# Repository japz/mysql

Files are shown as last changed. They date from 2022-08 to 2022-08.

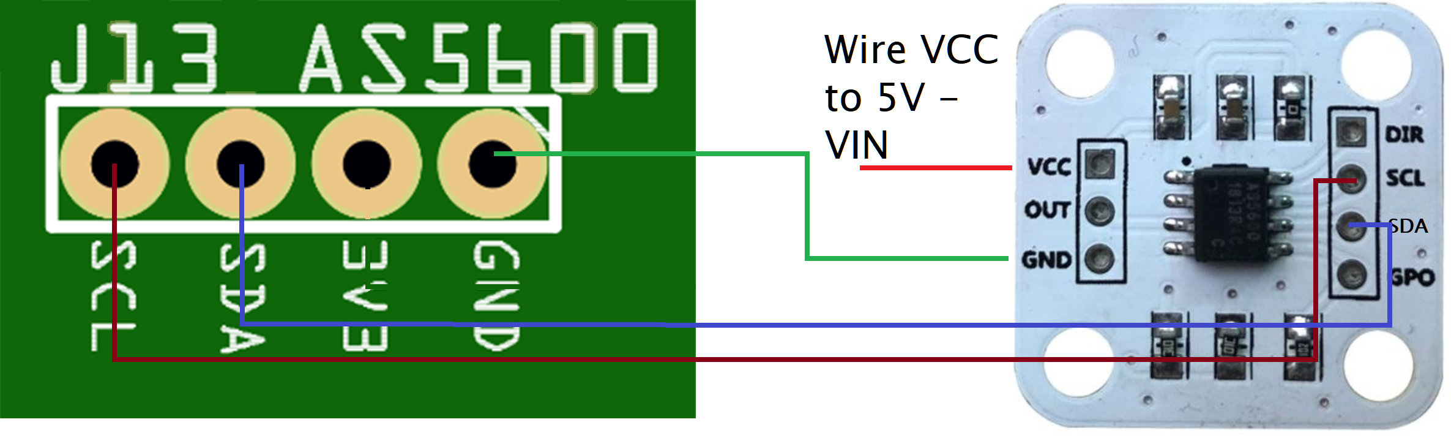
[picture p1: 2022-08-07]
Wind Direction Sensor/WINDDIRECTION3DPRINT/Wind-Direction-3DPRINT-Sensor-Wiring-Rev5-Rev6-Rev7.png

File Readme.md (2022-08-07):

# mySQM+ SPECIFICATIONS
(c) R Brown 2020-2022. All rights reserved  

## SPECIFICATIONS
 - Displays sky quality reading mag/arc-seconds
 - Use manually or via a network via TCP/IP, with logging capability
 - Web server option to provide data in a web-browser
 - Admin web-page function, most options can be enabled/disabled without reprogramming controller
 - Comprehensive manual
 - Easy to expand, examples of using remote iOT sensors
 - use mySQMWeb feature to provide running of web-based graphical interface on Pi
 - Settings saved in SPIFFS, remembered when power is off
 - SQM reading
 - Lux reading
 - NELM reading
 - Rain sensor
 - GPS [NEO-6M]
 - JSON support
 - MQTT support, publish values to an MQTT Broker, subscribe to topics
 - Weather Underground support
 - Real Time Clock [RTC] support [DS1307]
 - Network Time Protocol [NTP] support, Sync RTC to NTP data
 - OTA [Over the Air] update support
 - Ambient temp, dewpoint, humidity, pressure
 - IR Sky temp, IR Sky ambient temp
 - Cloud sensor and modelling indicating Clear, Cloudy and Percentage
 - Anemometer Wind speed sensor [multiple types supported] [3d print version available]
 - Wind direction sensor [multiple types supported] [3d print version available]
 - Wind Chill Factor
 - Beaufort Scale for Windspeed
 - Rain Bucket Gauge
 - OLED Text and Graphic display
 - Support for Sparkfun SENS-08942 Weather Kit [Anemometer, Wind Direction, Rain Bucket Gauge]
 - Support for Misol Weather Kit [Anemometer, Wind Direction, Rain Bucket Gauge]
 - PCB [gerbers available online for free]
 - Web-browser for remote operation
 - Windows application (Windows 11, 64 bit)
 - Linux application and source code
 - ASCOM OC driver, tested with NINA
 - Support for myESP32 Daughter Board's with remote sensors for Rainfall, Lightning and UV
 - Requires 12V PSU at 2A

## PCB
PCB Gerbers free, upload the Gerber files to any on-line PCB facility

## CONTRIBUTIONS
To support ongoing development please send your donation via https://PayPal.com to user rbb1brown@gmail.com (Robert Brown).

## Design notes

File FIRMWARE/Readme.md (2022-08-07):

# mySQM+ SPECIFICATIONS
(c) R Brown 2020-2022. All rights reserved  

# FIRMWARE
 - Download the firmware zip file
   https://sourceforge.net/projects/mysqmproesp32/files/FIRMWARE/

 - Extract the files
 - Install the required library myOLED
 - Download/add the required Additonal libraries
 - Download/install the Sketch data file upload tool
 - Specify the configuration in the configuration file
 - Program the controller
 - Upload the sketch data files

# APPLICATIONS
 - ASCOM OC Driver 
  https://sourceforge.net/projects/mysqmproesp32/files/APPLICATIONS/ASCOM/
 - Linux 
  https://sourceforge.net/projects/mysqmproesp32/files/APPLICATIONS/LINUX/
 - Windows
  https://sourceforge.net/projects/mysqmproesp32/files/APPLICATIONS/WINDOWS/
  - Documentation
  https://sourceforge.net/projects/mysqmproesp32/files/DOCUMENTATION/

Root Folder 
https://sourceforge.net/projects/mysqmproesp32/files/

 - Support for myESP32 Daughter Board's with remote sensors for Rainfall, Lightning and UV
 - Requires 12V PSU at 2A

## PCB
PCB Gerbers free, upload the Gerber files to any on-line PCB facility

## CONTRIBUTIONS
To support ongoing development please send your donation via https://PayPal.com to user rbb1brown@gmail.com (Robert Brown).

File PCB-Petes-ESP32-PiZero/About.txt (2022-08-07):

Pete's PCB for ESP32 + Pi Zero on one board

The Pi-Zero is to run mySQMWEB.

The ESP32 runs the various sensor devices, webserver and other functions.

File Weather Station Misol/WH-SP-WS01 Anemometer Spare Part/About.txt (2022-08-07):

https://www.aliexpress.com/item/32793283814.html

Spare part (outdoor unit) for Professional Wireless Weather Station, WH-SP-WS02

US $41.38

1). thermo-hygro sensor (1 unit)
2). Wind direction sensor (1 unit)
3). Rain gauge sensor (1 unit)
4). Wind speed sensor (1 unit)
5). Installation rack (1 unit)

https://openweatherstation.com/ows/index.php

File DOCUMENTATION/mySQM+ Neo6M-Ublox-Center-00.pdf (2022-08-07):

# mySQM+ NEO-6M GPS AND UBLOX CENTER

14 February 2022
(c) R BROWN 2022
All rights reserved.

This document outlines the initial configuration of the NEO-6M GPS module using UBLOX Center evaluation software.

## UBLOX CENTER FOR WINDOWS

I am using uBLOX-Center Windows exe 21.09 which you will need to download.

### Connection

Connect up GPS unit to a RS232-USB convertor as indicated below

NEO6M-Pin | RS232/USB
VCC | VCC
RXD | TXD
TXD | RXD
GND | GND

## START UBLOX-CENTER

### Set the COM Port Speed to 9600

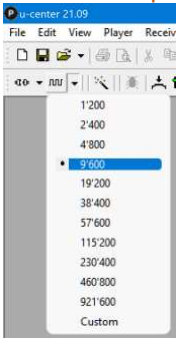
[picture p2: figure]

### Set the COM Port

Click on the Down arrow of the Com Port, select the port and Click Connect

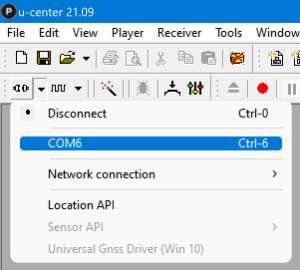
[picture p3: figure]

### Open the text console

Use the menu View-Text Console. You may see a heap of text messages in the Text Console window

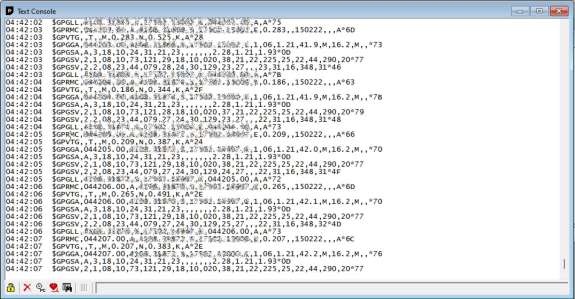
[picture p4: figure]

### Open the Message console

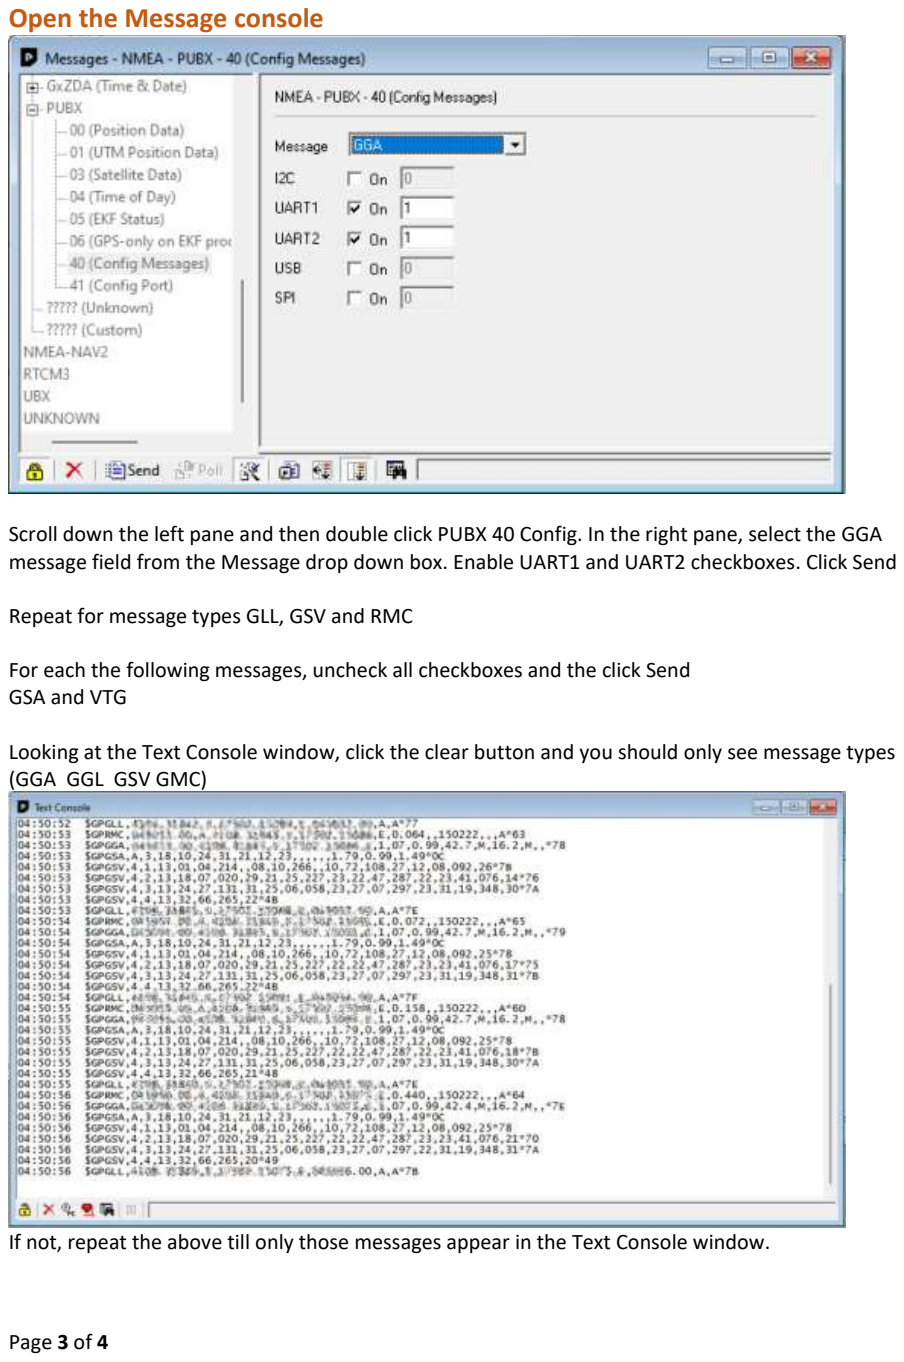
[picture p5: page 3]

Scroll down the left pane and then double click PUBX 40 Config. In the right pane, select the GGA message field from the Message drop down box. Enable UART1 and UART2 checkboxes. Click Send

Repeat for message types GLL, GSV and RMC

For each the following messages, uncheck all checkboxes and the click Send
GSA and VTG

Looking at the Text Console window, click the clear button and you should only see message types (GGA GGL GSV GMC)

If not, repeat the above till only those messages appear in the Text Console window.

### DOCKING WINDOWS

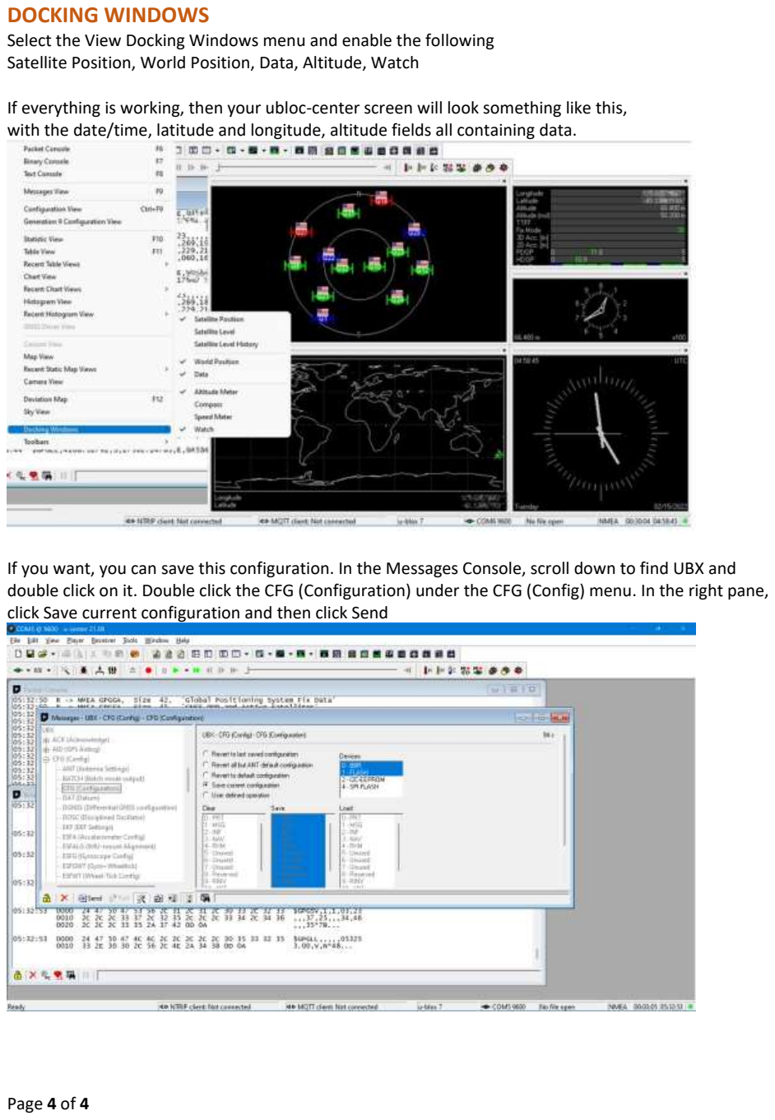
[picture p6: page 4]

Select the View Docking Windows menu and enable the following
Satellite Position, World Position, Data, Altitude, Watch

If everything is working, then your ubloc-center screen will look something like this, with the date/time, latitude and longitude, altitude fields all containing data.

If you want, you can save this configuration. In the Messages Console, scroll down to find UBX and double click on it. Double click the CFG (Configuration) under the CFG (Config) menu. In the right pane, click Save current configuration and then click Send

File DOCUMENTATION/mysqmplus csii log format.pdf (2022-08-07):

### mySQM+ CLOUD SENSOR II FORMAT

- Connect to controller
- Enable checkbox CSII Format
- Set logging interval
- Enable Automate logging
Date/Time | yyyy-MM-dd HH:mm:ss.ss
Temperature | C | values in Celsius
Wind Velocity | m | meters per second
Sky temperature | IRObject Temperature
Ambient temperature | IRAmbientTemp
Sensor case temperature | bme280temperature
Wind Speed | in m/s
Humidity | bme280humidity
Dew Point | bme280dewpoint
Heater % | 0
Rain Flag | Raining or Not raining
Seconds since the last valid data | timerinterval tick / 1000
Now | 038506.08846
c | sky state | skystate
w | wind condition | 0
r | rain condition | Raining or Not raining
d | daylight condition | lux
C | roof close | 0
A | Alert | 0

### Skystate

Cloud cover percentage ( 0-100% ) is used to generate the cloud condition value in the CSII log.

// 94 c sky state, cloudUnknown = 0, cloudClear = 1, cloudCloudy = 2, cloudVeryCloudy = 3
If cloudcover > 59.9 then cloudstate = 3; | // cloudVeryCloudy
else if cloudcover > 33.9 AND cloudcover < 59.9 then cloudstate = 2; | // cloudCloudy
else cloudstate = 1 | // cloudClear

if cloudcover > cloudVeryCloudy then cloudstate = 3
else if cloudcover > cloudCloudy AND cloudcover < cloudVeryCloudy then cloudstate = 2 else cloudstate = 1

cloudVeryCloudy is the top boundary [default is 59.9]. Any cloudcover value greater than this results in a value of 3 for cloudstate

cloudCloudy is the middle boundary [default is 33.9]. Any cloudcover value greater than the cloudCloudy boundary value AND if the cloudcover value is less than the cloudVeryCloudy value, results in a value of 2 for cloudstate

cloudClear is the lower boundary. Any cloudcover less than the cloudCloudy value results in a value of 1 for cloudstate

### Wind Condition

To do this we compare windspeed (remember some sensors have a maximum limit reading of 20 m/s) against some arbitrary boundaries to generate a wind condition.

// 96 w wind condition, windUnknown = 0, windCalm = 1, windWindy = 2, windVeryWindy = 3
If windspeed >= 15.0 then windcondition = 3 | // windVeryWindy
else if windspeed >= 5.0 and windspeed < 15.0 then windcondition = 2 // windWindy
else windcondition = 1 | // windCalm

if windspeed >= windVeryWindy then windcondition = 3
else if windspeed >= windWindy and windspeed < windVeryWindy then windcondition = 2 else windcondition = 1

windVeryWindy is the top boundary [default is 15.0]. Any windspeed value greater than this results in a value of 3 for windcondition

windWindy is the middle boundary [default is 33.9]. Any windspeed value greater than the windWindy value AND less than the windVeryWindy value, results in a value of 2 for windcondition

windCalm is the lower boundary. Any windspeed value that is less than the windWindy value results in a value of 1 for windcondition

### Daylight Condition

The lux value is compared against some arbitary boundaries to generate a daylight condition.

// (100) d daylightcondition, dayUnknown = 0, dayDark = 1, dayLight = 2, dayVeryLight = 3
if lux >= 5000.0 then daylightcondition = 3 | // dayVeryLight
else if lux >= 5.0 AND lux < 5000.0 then daylightcondition = 2 | // dayLight
else daylightcondition = 1 | // dayDark

// (100) d daylightcondition, dayUnknown = 0, dayDark = 1, dayLight = 2, dayVeryLight = 3 if lux >= dayVeryLight then daylightcondition = 3
else if lux >= dayLight AND lux < dayVeryLight then daylightcondition = 2
else daylightcondition = 1

dayVeryLight is the top boundary [default is 5000.0]. Any lux value greater than this results in a value of 3 for daylightcondition

dayLight is the middle boundary [default is 5.0]. Any lux value greater than the dayLight value AND less than the dayVeryLight value, results in a value of 2 for daylightcondition

dayDark is the lower boundary. Any lux value that is less than the dayLight value results in a value of 1 for daylightcondition

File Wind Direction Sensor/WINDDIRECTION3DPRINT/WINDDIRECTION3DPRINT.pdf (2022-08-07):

1 | P a g e

## mySQMPROESP WINDDIRECTION3DPRINT SENSOR

© Robert Brown, 2020. All rights reserved.

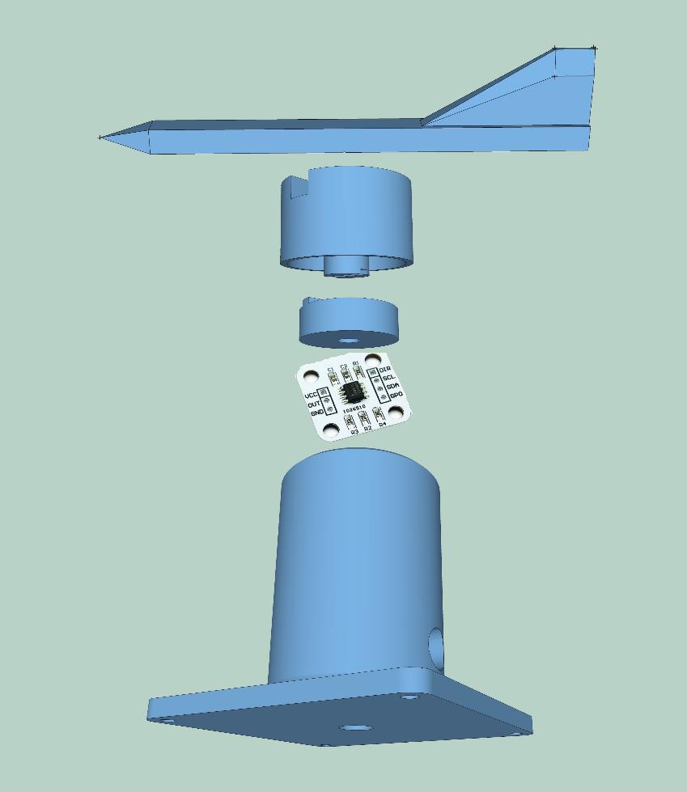
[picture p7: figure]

//TODO Replace picture with finished unit

2 | P a g e

## Contents

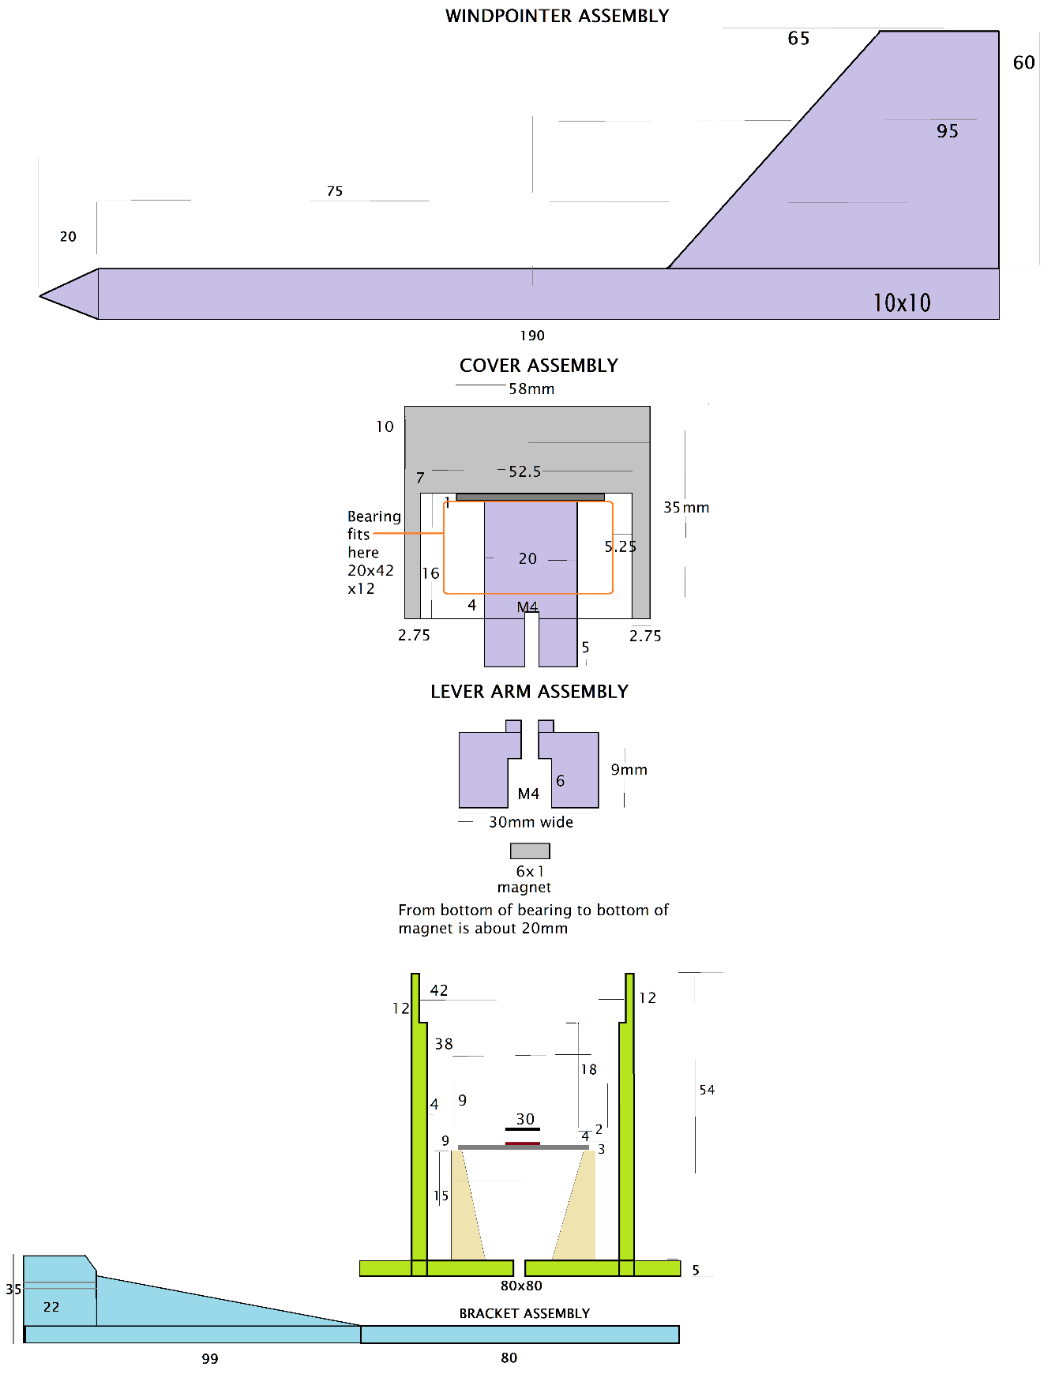
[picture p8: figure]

3 | P a g e

## OVERALL DESIGN PRINCIPLES

DIMENSIONS

4 | P a g e

WINDPOINTER TIP ASSEMBLY
The wind pointer tip has a hollow portion to allow a small lead ballast to be fitted before assembly to the front of wind pointer assembly [push interference fit – secure with super glue or hot glue]. The ballast helps in pointing ability.

WINDPOINTER ASSEMBLY
The wind vane mounts into the 10mm recess groove on the top of the cover assembly. A small notch in the wind vane arm and center M3 bolt hole helps positioning the vane appropriately on the cover assembly. There are two designs [1, 2] which have different wind vane heights. One or the other may be more suited to your local conditions [the larger height should give better results in low wind environments]

COVER ASSEMBLY

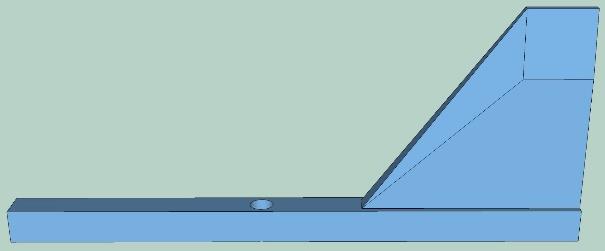
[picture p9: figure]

The cover assembly forms the rotating head of the sensor with a magnet attached. A large 6004 2RS low friction bearing is used to allow a center column diameter of 12mm, providing ample strength to handle strong winds. At the bottom of the center column is fitted a lever arm [using a slotted recess and a M4 x 10mm hex bolt]. A small round magnet [6mmx1mm] fits onto the head of the hex bolt [and secured in place with super glue or hot glue]. The cover assembly when completed is attached to the Base assembly by press fitting the bearing into the recess of the base assembly and is held in place by an interference fit.

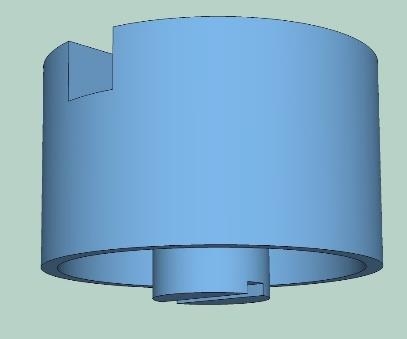
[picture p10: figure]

5 | P a g e

LEVER ARM ASSEMBLY
The lever arm is slotted to fit into a recess at the bottom of the center column of the Cover assembly. It is held in place with a M4 x 10mm hex bolt. The small 6mmx3mm magnet is fitted into a recessed hole in the bottom of the Lever Arm assembly and glued into place using hot glue. The lever arm assembly rotates as the cover assembly rotates and the magnet rotates with it, just above the sensor. If the AS5600 sensor module is mounted underneath the lever arm [sensor directly underneath magnet with air spacing 3-5mm], the magnet will pass over the module generating an angle indication representing the direction.

BASE ASSEMBLY
This assembly has an 80x80mm square plate 5mm thick to allow connection to a post or optional mounting arm bracket. A 10mm hole in the base plate allows for water drainage if by some reason water enters the assembly. A 12mm hole is provided for the GX12 4P connector. At the top of the base unit, a 42mm recess is used which will house the 6004 2RS low friction bearing. The wall thickness of the base unit is 6mm to provide strength. The AS5600 module is secured to the center of the base assembly at the specified location, ensuring that the module can detect the magnet as it passes near to it.

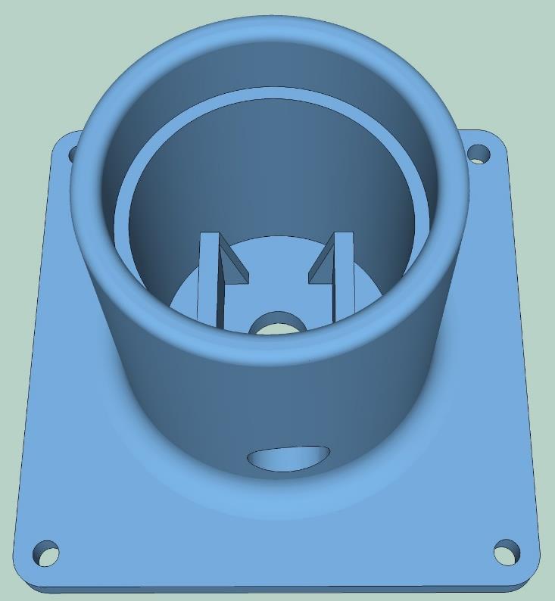
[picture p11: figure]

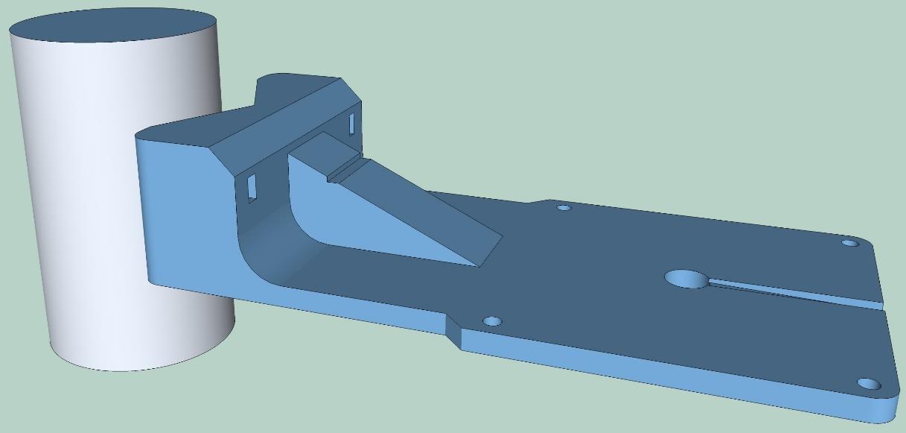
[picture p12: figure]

6 | P a g e

OPTIONAL MOUNTING BRACKET
The optional mounting bracket is for mounting the anemometer on a 2.54mm [1”] diameter pole. Two plastic zip ties can be used to secure the bracket to the pole, and the anemometer can be bolted to the bracket using [4] M4x15mm bolts.

The center hole and 4mm wide sloping trough allows water to escape.

7 | P a g e

## PARTS LIST

Quantity | Item
1 | Wind Pointer Tip Assembly
1 | Wind Pointer Assembly
1 | Base Assembly
1 | Cover Assembly
1 | Lever arm Assembly
3 | Cup and Arm Assembly
2 | Hex bolt 4M x 10mm
1 | Bearing 6004 2RS low friction, 20x42x12mm [ID/OD/Thickness]
1 | AS5600 Magnetic angle sensor and magnet
1 | Small round magnet 6mm round, 3mm deep [optional]
1 | GX12 4P Aviation male connector, waterproof, 12mm diameter
1 | GX12 4P Aviation female connector, 12mm diameter
1 | 3M 3-core weather proof cable

AS5600 Magnetic Sensor and Magnet Aliexpress DEXIANG Store https://www.aliexpress.com/item/4000861019000.html
$2.30USD

NOTE: YET TO DECIDE ON 6x1 MAGNET OR 6x3 MAGNET: NEED MORE TESTS

Magnet 6mm x 3mm N35 Round Magnets Aliexpress YCHEN Store https://www.aliexpress.com/item/32953346950.html
$2.47USD

Bearing, 20x42x12mm Alixexpress wuhushiyu Store https://www.aliexpress.com/item/4000038143034.html $2.82USD

8 | P a g e

GX12 4P Connector, male and female pair push weatherproof Aliexpress ATOPELEC Store [Note: This is for 2 sets, the other one can be used for the Wind Direction Sensor] https://www.aliexpress.com/item/32831416252.html
$2.25

9 | P a g e

## PRINT INSTRUCTIONS

Nozzle | 0.4mm
Layer Height | 0.2mm
Print Speed | 30
Infill | 10% | [Windpointer = 20%, LeverArm infill = 100%]
Supports | No | [Cover, Windpointertip, Base = Supports]

I used PLA in the prototype. PLA exposure to sun and weather will deteriorate as PLA is based on corn starch. Might be okay is painted to protect PLA from elements.

Recommend PETG for usage. PETG is strong and low shrinkage.

Do not recommend ABS due to shrinkage.

Cover Assembly
≈ 3 hours print time

WindPointerTip Assembly
≈ ½ hours print time

WindPointer Assembly
≈ 2½ hours print time

LeverArm Assembly
≈ 1 hours print time

Base Assembly
≈ 6 hours print time

Mounting Bracket Assembly
≈ 6 hours print time

10 | P a g e

## ASSEMBLY INSTRUCTIONS

WINDPOINTER TIP ASSEMBLY
- Fit a small amount of lead to the hollow recess of the pointer tip
- Secure the wind pointer tip in place by inserting it into the recess of the end of the Windpointer assembly [super glue or hot glue]

WINDPOINTER ASSEMBLY
- The wind pointer fits into the 10mm deep grove of the cover assembly
- To work effectively, there is a small groove on the base side of the wind pointer assembly. This groove is to help position the wind pointer on the cover assembly
- Position the wind pointer so the groove is over the center point of the cover assembly. Secure the wind pointer in place with an M4x10mm hex bolt [do not overtighten]

BASE ASSEMBLY
GX12 Connector wiring to AS5600 board
- Solder 4 different colored wires (80-100mm) to GX12 connector pins, slip heat shrink tube over solder connections and apply heat to shrink tube
- Using a flat file, slightly file the hole for the GX12 connector to create a slight flat surface. Do not take off too much material, only 1mm is enough
- Fit GX12 connector to the base assembly by inserting into 12mm hole at base and tighten lock nut (do not overtighten). You can use a rubber washer on the outside to prevent possible water leakage [the rubber waterproof ring is sufficient]
- Wire connector to AS5600 module [3V3 to VCC, GND, SDA and SCL], use heat-shrink tube, ensure correct wires go to correct pins
- Secure AS5600 module in place at the specified place with hot glue gun. Ensure there is a small gap (3-5mm) between the magnet and the AS5600 module.

COVER AND LEVER ARM ASSEMBLY
- Fit Bearing to Cover center column
- Connect Lever Bar to Cover center column. Secure with M4 bolt, do NOT overtighten
- Mount Magnet in Lever Bar in recess hole for M4 on top of hex bolt, secure with super glue or hot glue
- Insert cover into place in Base by positioning Cover assembly over Base and pressing downwards till bearing is fully inserted in Base assembly

11 | P a g e

ASSEMBLY PHOTOS

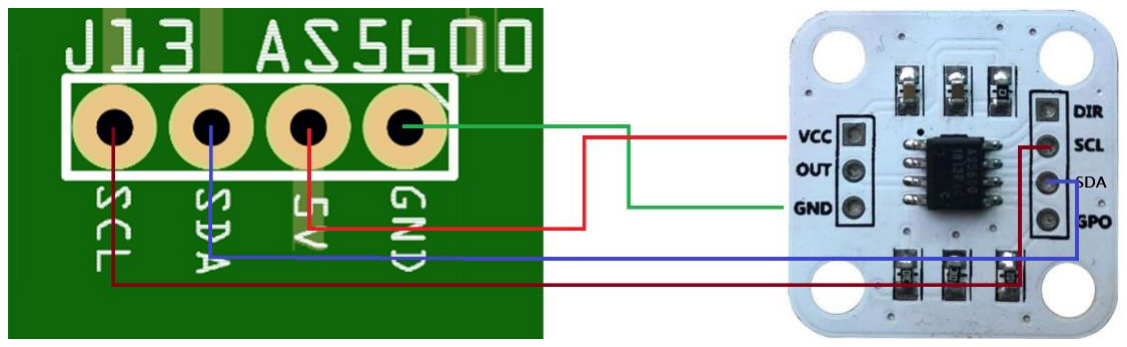
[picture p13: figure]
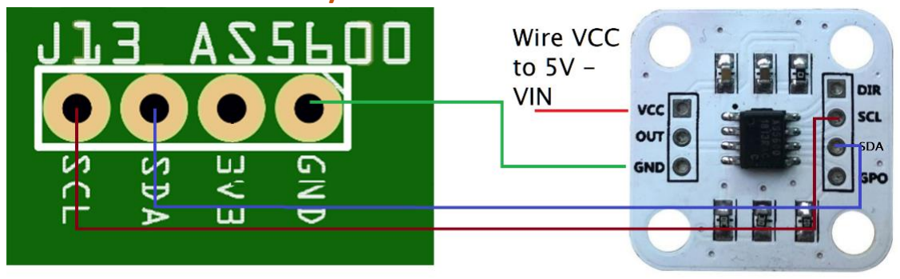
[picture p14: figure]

12 | P a g e

## WIRING

AS5600 MODULE PCB8

AS5600 MODULE PCB6/7

13 | P a g e

## TESTING THE WINDDIRECTION 3DPRINT SENSOR

Use the test program TEST_WINDDIRECTION3DPRINT.ino to test the wind direction sensor. There is no need to calibrate the unit if you followed the instructions and did not change any of the print size measurements.

Mount the sensor on the bracket and secure in place.

Use the test program determine the 0 angle position.

Carefully holding the wind vane in place, rotate the entire assembly so that the front of the wind vane is pointing due NORTH. Secure the assembly in place.

Reload the controller with the mySQMPROESP firmware, with the WINDDIRECTIONSENSOR and WINDDIRECTION3DPRINT defined in controllerconfig.h

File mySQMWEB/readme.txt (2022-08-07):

mySQMWEB
A graphical web based interface running on Apache or Raspberry PI that takes the values from a mySQM+ controller to a graphical Web page(s)

Please view the video and see values change in real time.

Please view the PDF in this zip file for instructions on how mySQMWEB can be installed.
https://sourceforge.net/projects/mysqmproesp32/files/mySQMWEB/

For further information, download the PDF for this project
https://sourceforge.net/projects/mysqmproesp32/files/DOCUMENTATION/

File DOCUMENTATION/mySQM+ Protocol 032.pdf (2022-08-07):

## mySQM+ PROTOCOL 032

May 2022
(c) R BROWN 2020-2022
All rights reserved.

APPLICABLE TO FIRMWARE 128-35+

### INTERFACE COMMANDS - TCP/IP, PORT 2121

- All commands are a string of char characters
- All send commands begin with a colon character :
- All commands have a minimum of three digits (0-9).
- All commands end with a hash character #
- Commands are zero padded from the left to three places, for example, command 2 is written as :002#

RETURN VALUES
- All return values are terminated with a #
- All return values are string characters, numbers are converted to strings before sending
Send | Meaning
:000# | Get System up-time
:001# | Reboot controller
:002# | Get MAC Address
:003# | Get SQM
:004# | Get LUX
:005# | Get NELM
:006# | Get make hay
:007# | Get services: returns Controllermode, Webserver state, TCPIP Server state,
| OTA state, MQTT client state, mqtt connect state, NTP client state,
| Management server state

FIRMWARE
:008# | Get firmware version number
:009# | Get firmware filename
:010# | Get firmware hash value

DISTANCE MODE
:011# | Get metric/imperial mode 0 = metric 1 = Imperial
:0120# | Set metric
:0121# | Set imperial

TEMPERATURE MODE
:013# | Get temperature mode (0=Celsius 1=Fahrenheit)
:0140# | Set temperature mode Celsius
:0141# | Set temperature mode Fahrenheit

TLS2591
:017# | Get tlscorrectionfactor
:018# | Get TSL2591 Gain
:019# | Get TSL2591 Integration time
:020# | Get TSL2591 sample size
:021# | Get TSL2591 averaging (0=Disabled, 1= Enabled)
:022n.n# | Set TLS sensor correction factor
:023n# | Set TSL2591 Gain
:024n# | Set TSL2591 Integration time
:025n# | Set TSL2591 sample size
:0260# | Set TSL2591 averaging OFF
:0261# | Set TSL2591 averaging ON

:027# UNUSED

BME280
:028# | Get Relative Humidity
:029# | Get Pressure
:030# | Get Ambient temperature
:031# | Get Dewpoint
:032# | Get Altitude (in meters)
:033# | Get Pressure adjusted to sea-level
:034x.x# | Set Altitude (float in meters)

MLX90614
:035# | Get IR Sensor object temperature
:036# | Get IR Sensor ambient temperature
:037# | Get Sky-State, 0=clear 1=partly cloudy 2=cloudy
:038# | Get % Cloud Cover
:039# | Get corrected sky value
:040# | Get cloud sensor k1 - k7 values k1,k2,..k7#
:041# | Get Temp Clear
:042# | Get Temp Overcast
:043# | Get Cloud-Flag-Percent
:044x,x# | Set cloud model k1..k7, separated by ,
:045n# | Set Temp Clear (-8)
:046n# | Set Temp Overcast (0)
:047n# | Set Cloud-Flag-Percent (30)

RAIN
:048# | Get rain total in mm over previous hour
:049# | Get Raining (Boolean)
:050# | Get RVout - raining analogue value (int)
:051# | Get cumulative rainfall for this current hour
:052# | Get cumulative rainfall for this current day
:053# | Do Sync Rain Bucket Gauge min/hour to RTC

WIND
:054# | Get wind speed (in meters per second)
:055# | Get wind direction
:056# | Get Wind Chill Factor
:057# | Get windspeed sensor name and wind direction sensor name
:058# | Get average windspeed last 30s
:059# | Get maximum wind speed gust last 30s
:015# | Get wind direction offset
:016n# | Set wind direction offset (unsigned int 0-359)

GPS
:060# | Get local date
:061# | Get local time
:062# | Get latitude
:063# | Get longitude
:064# | Get altitude (height in meters)
:065# | Get number of satellites
:066# | Get GPS fix
:067# | Get if GPS using static co-ordinates [0=No 1=Yes]
:068# | Get if GPS using truncated co-ordinates [0=No 1=Yes]
:069# | Get GPS Fix 'es,
| gga_quality_indicator, gll_fix_status, gll_position_mode_indicator,
| rmc_mode_indicator, gsa gsa_smode, gsa_navmode
:070# | Get GPS Static Latitude setting
:071# | Get GPS Static Longitude setting
:072# | Get GPS Format (0=DD, 1=DMS)
:0730# | Set GPS Format DD
:0731# | Set GPS Format DMS
:0740# | Set GPS use static co-ordinates OFF
:0741# | Set GPS to use static co-ordinates ON
:0750# | Set GPS truncated state OFF
:0751# | Set GPS truncated state ON
:076ss# | Set GPS Static Latitude setting (string)
:077ss# | Set GPS Static Longitude setting (string)

DISPLAY
:078# | Get display enabled state
:079# | Get page display option [String]
:080# | Get page display time [unsigned int]
:0810# | Set Display enabled state OFF
:0811# | Set Display enabled state ON
:082ss# | Set page display option [String]
:083nnnn# | Set page display time [unsigned int 2000-10000] in milliseconds

RTC
:084# | Get RTC date/time string dd/mm/yr,hh:mm:ss]
:085# | Get SYNC RTC to NTP, if NTP should sync date/time to RTC
:086ss# | Set RTC date/time mm,dd,yyyy,hr,mn,ss
:0870# | Set SYNC RTC to NTP state OFF
:0871# | Set SYNC RTC to NTP state ON

MANAGEMENT SERVER
:088# | Get Management Server state (0=Stopped=0, 1=Running)
:089# | Get Management Server Port number
:090nn# | Set Management Server Port number
:0910# | Set Management Server state OFF
:0911# | Set Management Server state ON

MQTT
:092# | Get MQTT Subscribe topic
:093# | Get MQTT Server state (Start=1, Stop=0)
:094# | Get MQTT Broker IP address
:095# | Get MQTT Publish Topic
:096# | Get MQTT Publish Interval
:097# | Get MQTT Subscribe Enable state
:098ss# | Set MQTT Subscribe topic
:099ss# | Set MQTT Broker IP address
:100ss# | Set MQTT Publish Topic
:101n# | Set MQTT Publish Interval
:1020# | Set MQTT Server state OFF
:1021# | Set MQTT Server state ON
:1030# | Set MQTT Subscribe state OFF
:1031# | Set MQTT Subscribe state ON

NTP
:104# | Get NTP Time one string
:105# | Get NTP Client state (0=Stopped=0, 1=Running)
:106# | Get NTP UTC date/time string [dd/mm/yr,hh:mm:ss]
:107# | Get NTP LOC [UTC adj by TZ] date/time string [dd/mm/yr,hh:mm:ss]
:108# | Get NTP Servername
:109# | Get NTP Update interval (in minutes)
:110ss# | Set NTP Servername
:111n# | Set NTP Update interval (in minutes, )
:112s# | Set NTP Time zone (this will also restart the NTP Client
:113# | Restart NTP Client (Reserved for future use)
:1140# | Start NTP Client (Reserved for future use)
:1141# | Stop NTP Client (Reserved for future use)

WEBSERVER
:115# | Get webserver port
:116# | Get webserver state (0=Stopped, 1=Running)
:117# | Set webserver port
:1180# | Set Webserver state OFF
:1181# | Set Webserver state ON

# WEB SERVER

There is significant JSON support built into the web server functionality.

### HOME PAGE FORMAT: HTML OR JSON

Management Server /admin3 page provides the option of sending the Home Page of the Web Server in either HTML format or in JSON format.

In the screenshot, the current format setting for the home page is HTML (the current format state is shown between [].

The button shows what the home page format state will change to when clicked by the user.

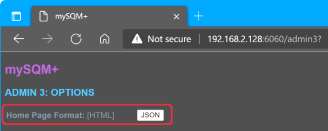
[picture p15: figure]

Clicking on the JSON button will change the home page format to JSON, and any request for the home page will be sent a JSON string.

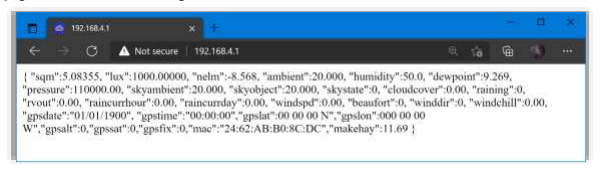
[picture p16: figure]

This can be useful if you want to write your own applications to communicate with the controller. The client application is responsible for connecting to the controller and sending a GET root page / request to the Web Server.

All parameters are lowercase and values are returned in CELSIUS and METRIC. The client application is responsible for converting any values to FAHRENHEIHT or IMPERIAL units of measurement.

This call obeys the rules for truncate gps and static gps. The gps co-ordinates are derived from the static gps co-ordinates, use static gps is enabled, and truncate gps is enabled on the Management Server page /admin2

Using the Home Page customizations, you can decide what values/settings appear on the Webserver’s Home Page, for both HTML and JSON formats.

### USING THE WEB SERVER WITH CLIENT APPLICATIONS

Client applications (such as Curl) can establish a connection to the Web Server on port 80. Using this port, the application can request the groups of data corresponding to various functions of the controller. A request returns a JSON formatted string. All requests and responses are lowercase.

WEBSERVER GROUPS AND JSON RESPONSES
The home page of the Web Server lists values under the main headings of Temperature, Dark Sky, Weather and GPS. These groups can be retrieved using the following requests

/d1
An application sending /d1 receives a JSON string response of the “DARKSKY” variables.

{ "sqm":25.08356,"nelm":7.536,"lux":0.00,"skystate":1,"cloudcover":100.00 }

/g1
An application sending /g1 t receives a JSON string response of the “GPS” variables. This call obeys the rules for truncate gps and static gps. To convert UTC to LOC, firmware uses the TimeZone and TZ string values from the /admin6 Management server page (NTP settings).

{ "gpsdate":"01/01/1900","gpstime":"00:00:00","gpslat":"00 00.000000 N","gpslon":"00 00.000000 E","gpsalt":0, "gpssat":0,"gpsfix":0 }

/rd
An application sending /rd receives a JSON string response of ALL dynamic values except GPS.

{
"sqm":12.21815,"nelm":-1.461,"ambient":20.000,"humidity":50.0,"dewpoint":9.269, "pressure":1100.00,"skyambient":20.000,"skyobject":20.000,"lux":1.40011,"skystate":0, "cloudcover":0.00,"raining":0,"rvout":0.00,"windspd":0.00,"beaufort":0,"winddir":0
}

/t1
An application sending /t1 receives a JSON string response of the “TEMPERATURE” variables.

{ "ambient":20.000,"dewpoint":9.269,"skyambient":23.850,"skyobject":23.690 }

/w1
An application sending /w1 receives a JSON string response of the “WEATHER” variables.

{ "humidity":50.0,"pressure":110000.00,"raining":0,"rvout":0.00,"raincurrhour":0.00, "raincurrday":0.00,"windspd":0.00,"beaufort":0,"winddir":0 }

WEBSERVER REQUESTS AND JSON RESPONSES
The following requests return a JSON string of the requested values.

/about
An application sending /about receives a JSON string response of the controller details.

{ "product":"mySQM+","Author":"R. Brown, 2020-2021.","ver":"120" }

/date
An application sending /date receives a JSON string response for the local date and time. Which date and time is sent to the client is subject to the LOCALDATETIMESOURCE on the /admin web page.

{ "local":"02/12/2021,21:28:35","source":"rtc" }

/gps
An application sending /gps receives a JSON string response for the gps values and settings.

{ "gpsdate":"01/01/1900","gpstime":"00:00:00","gpslat":"-77 00 00 S","gpslon":"166 00 00 E","gpsalt":0.0,"gpssat":0,"gpsfix":0 }

/ gpsgga
An application sending /gpsgga receives a string response for the last received NMEA message.

/gpsgll
An application sending /gpsgll receives a string response for the last received NMEA message.

/gpsrmc
An application sending /gpsrmc receives a string response for the last received NMEA message.

/mac
An application sending /mac receives a JSON string response of the MAC address value.

/makehay
An application sending /makehay receives a JSON string response of the vpd value (make hay < 10 is good) value.

/mqtt
An application sending /mqtt receives a JSON string response of the MQTT broker IP and connection details [if enabled].

/ntp
An application sending /ntp receives a JSON string response of the NTP local date and time dynamic values [if enabled].

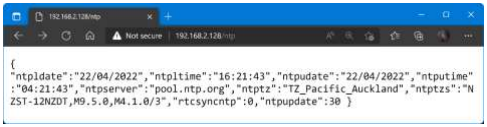
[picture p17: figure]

/rain
An application sending /rain receives a JSON string response of the rain information [if enabled].

/rbgsync
An application sending /rbgsync receives a JSON string response (Ok or nok) of the controllers attempt to synchronise the rain bucket gauge to the Real Time Clock.

/rtc
An application sending /rtc receives a JSON string response of the Real Time Clock dynamic values [if enabled].

/tsl
An application sending /tsl receives a JSON string response of the TLS2591 sensor settings

/uptime
An application sending /uptime receives a JSON string response of the system uptime. The format is days:hours:minutes

CUSTOM JSON RESPONSES (from file customjson.h)

/cj1
{ "windspeed":0.00,"winddirection":0 }

/cj2
{ "sqm":10.38279,"nelm":-3.280,"lux":2.29704 }

WEB SERVER XHTML SUPPORT
The Web Server supports direct XJTL requests, where the value of the requested item is returned. The home page of the webserver as an HTML page has embedded scripts in the page that send XHTML requests to the server, and the responses are used to dynamically update the web page contents.

This means that you do not need to use REFRESH to get an updated page with new values, because the home page does this dynamically without having to request the home page again.

XHTML Request | Value returned
/ba | ambient
/bh | humidity
/bd | dewpoint
/bp | pressure
/ma | skyambient
/mo | skyobject
/sq | sqm
/ne | nelm
/lu | lux
/ss | skystate
/cc | cloudcover
/ra | raining
/rv | rvout
/rh | raincuurhr
/ry | raincurrday
/ws | windspd
/bs | beaufort
/wd | winddir
/wc | windchill
/ut | system_up_time
/mh | makehay

As an example of a sq request, the web server responds with the value of sqm at the time of the request

10.43037

# MANAGEMENT SERVER

The Management Server [port 6060] provides the following JSON queries.

/reboot
An application sending /reboot to the controller will cause the controller to reboot. There is no response to this request. After 6s, the page will refresh and directed to the / page of the Management server.

/reboottcp
An application sending /reboottcp to the controller will cause the controller to stop and then restart the TCP/IP-server service [used by TCP/IP applications in Windows and LINUX on port 2121].

/rebootws
An application sending /rebootws to the controller will cause the controller to stop and then restart the web-server service.

/rbgsync
An application sending /rbgsync to the controller will cause the controller to update the minute and hour values used by the Rain Bucket Gauge to that of the Real Time Clock. There is no response to this request.

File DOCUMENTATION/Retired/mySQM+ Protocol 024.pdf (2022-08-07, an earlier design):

## mySQM+ PROTOCOL 024

09 December 2021
(c) R BROWN 2020-2021
All rights reserved.

### INTERFACE COMMANDS - SERIAL OR TCP/IP

All send commands begin with a :
All send commands end with a #
All send commands are two digits followed by optional values (if setting a value)

RETURN VALUES
All return values are terminated with a #
All return values begin with a single character code to represent what the command was All return values are string characters so numbers are converted to strings before sending
Send | Return Code | Meaning
:03# | C | Get System up-time
:41# | | Reboot controller
:71# | Q | Get MAC Address
:01# | A | Get magnitude value (as float)
:21# | U | Get LUX value
:31# | Z | Get NELM
:A0# | ^ | Get make hay

BME280
:32# | a | Get BME820 humidity (app can calculate dew point from temp and humidity)
:33# | e | Get BME820 pressure
:34# | c | Get BME820 temperature
:35# | d | Get BME280 dewpoint
:A7# | $ | Get BME280 defined altitude (in meters, in place of gps_altitude)
:A8x.xx# | Set BME280 defined altitude (in meters)
:A9# | > | Get BME280 Pressure adjusted to sea-level

DISPLAY
:06# | F | Get display enabled state
:17x# | | Set display enabled [0 | 1]
:78# | 1 | Get page display option [String]
:79xxx# | | Set page display option [String]
:80# | 2xxxx# | Get page display time [unsigned int]
:81xxx# | | Set page display time [unsigned int 2000-10000] in milliseconds

DISTANCE MODE
:44# | j | Get metric/imperial mode 0 = metric 1 = Imperial
:45x# | | Set metric/imperial mode 0 = metric 1 = Imperial

FIRMWARE
:04# | D | Get firmware version number
:05# | E | Get firmware filename
:40# | h | Get firmware hash value

GPS
:08# | H | Get local date
:09# | I | Get local time
:10# | J | Get longitude
:11# | K | Get latitude
:12# | L | Get altitude (height in meters)
:13# | M | Get number of satellites
:16# | N | Get GPS fix
:18# | % | Get if GPS using static co-ordinates [0=No 1=Yes]
:30x# | | Set GPS to use static co-ordinates [0=Off 1=On]
:50# | @ | Get if GPS using truncated co-ordinates
:92x# | | Set GPS truncated [0=No 1=Yes]
:A1# | [ | Get GPS Static Latitude setting
:A2# | ] | Get GPS Static Longitude setting
:A3x# | | Set GPS Static Latitude setting
:A4x# | | Set GPS Static Longitude setting

MLX90614
:19# | O | Get IR Sensor object temperature
:20# | P | Get IR Sensor ambient temperature
:27# | V | Get cloudstate, 0=clear 1=partly cloudy 2=cloudy
:48# | t | Get % cloud cover
:49# | u | Get corrected sky value
:51# | m | Get k1 cloud model value
:52# | n | Get k2 cloud model value
:53# | o | Get k3 cloud model value
:54# | p | Get k4 cloud model value
:55# | q | Get k5 cloud model value
:56# | r | Get k6 cloud model value
:57# | s | Get k7 cloud model value
:58# | v | Get tempclear
:59# | w | Get tempovercast
:60# | x | Get cloudflagpercent
:61xx# | | Set k1 cloud model value
:62xx# | | Set k2 cloud model value
:63xx# | | Set k3 cloud model value
:64xx# | | Set k4 cloud model value
:65xx# | | Set k5 cloud model value
:66xx# | | Set k6 cloud model value
:67xx# | | Set k7 cloud model value
:68xx# | | Set temp clear (-8.0)
:69xx# | | Set tempovercast (0.0)
:70xx# | | Set cloudflagpercent (30.0)

MQTT
:07# | G | Get MQTT subscribe topic
:15String# | Set MQTT subscribe topic
:83# | 4String# | Get MQTT broker IP address
:84String# | Set MQTT broker IP address
:97# | !String# | Get MQTT Publish Topic
:98String# | Set MQTT Publish Topic
:A5# | <String# | Get MQTT Publish Interval
:A6String# | Set MQTT Publish Interval

NTP
:00# | z | Get NTP time zone string
:74# | b | Get NTP UTC date/time string [dd/mm/yr,hh:mm:ss]
:75# | y | Get NTP LOC [UTC adj by TZ] date/time string [dd/mm/yr,hh:mm:ss]
:77# | 0 | Get NTP servername
:85String# | Set NTP Servername
:88# | 6xx# | Get NTP minutes interval between RTC is synced to NTP
:89xx# | | Set minutes between syncing RTC to NTP
:99String# | Set NTP time zone

RAIN
:22# | 3 | Get rain total in mm over previous hour
:23# | R | Get Raining (Boolean)
:24# | S | Get raining analogue value (int)
:28# | W | Get cumulative rainfall for this current hour
:29# | X | Get cumulative rainfall for this current day
:82# | | Sync Rain Bucket Gauge min/hour to rtc

RTC
:72# | T | Get RTC date/time string dd/mm/yr,hh:mm:ss]
:94String# | Set RTC date/time mm,dd,yyyy,hr,mn,ss
:90# | 7x# | Get SYNC RTC to NTP, if NTP should sync date/time to RTC
:91x# | | Set SYNC RTC to NTP, if NTP should sync NTP date/time to RTC

TEMPERATURE MODE
:42# | i | Get temperature mode, 0=Celsius 1=Fahrenheit
:43x# | | Set temperature mode, 0=Celsius 1=Fahrenheit

TLS2591
:25# | 8 | Get tlscorrectionfactor
:26# | | Set TLS sensor correction factor
:36xx# | | Set TSL2591 Gain
:37xx# | | Set TSL2591 Integration time
:38# | f | Get TSL2591 Gain
:39# | g | Get TSL2591 Integration time

WIND
:46# | k | Get wind speed (in meters per second)
:47# | l | Get wind direction
:73# | Y | Get Wind Chill Factor
:86# | 5 | Get average windspeed last 30s
:87# | z | Get maximum wind speed gust last 30s

WEBSERVER
:02# | B | Get webserver port
:14xxxx# | Set webserver port
:95# | *x# | Get webserver state (0=Stopped 1=Running)
:96x# | | Start/Stop webserver (0=stop 1=start)

UNUSED
76
93

BY NUMBER
Send | Return Code | Meaning
:00# | z | Get NTP time zone string
:01# | A | Get magnitude value (as float)
:02# | B | Get webserver port
:03# | C | Get System up-time
:04# | D | Get firmware version number
:05# | E | Get firmware filename
:06# | F | Get display enabled state
:07# | G | Get MQTT subscribe topic
:08# | H | Get local date
:09# | I | Get local time
:10# | J | Get longitude
:11# | K | Get latitude
:12# | L | Get altitude (height in meters)
:13# | M | Get number of satellites
:14xxxx# | Set webserver port
:15String# | Set MQTT subscribe topic
:16# | N | Get GPS fix
:17x# | | Set display enabled [0,1]
:18# | % | Get if GPS using static co-ordinates [0=No, 1=Yes]
:19# | O | Get IR Sensor object temperature
:20# | P | Get IR Sensor ambient temperature
:21# | U | Get LUX value
:22# | 3 | Get rain total in mm over previous hour
:23# | R | Get Raining (Boolean)
:24# | S | Get raining analogue value (int)
:25# | 8 | Get tlscorrectionfactor
:26# | | Set TLS sensor correction factor
:27# | V | Get cloudstate 0=clear 1=partly cloudy 2=cloudy
:28# | W | Get cumulative rainfall for this current hour
:29# | X | Get cumulative rainfall for this current day
:30x# | | Set GPS to use static co-ordinates [0=Off 1=On]
:31# | Z | Get NELM
:32# | a | Get BME820 humidity (app can calculate dew point from temp and humidity)
:33# | e | Get BME820 pressure
:34# | c | Get BME820 temperature
:35# | d | Get BME280 dewpoint
:36xx# | | Set TSL2591 Gain
:37xx# | | Set TSL2591 Integration time
:38# | f | Get TSL2591 Gain
:39# | g | Get TSL2591 Integration time
:40# | h | Get firmware hash value
:41# | | Reboot controller
:42# | i | Get temperature mode 0=Celsius 1=Fahrenheit
:43x# | | Set temperature mode 0=Celsius 1=Fahrenheit
:44# | j | Get metric/imperial mode 0 = metric 1 = Imperial
:45x# | | Set metric/imperial mode 0 = metric 1 = Imperial

:46# | k | Get wind speed (in meters per second)
:47# | l | Get wind direction
:48# | t | Get % cloud cover
:49# | u | Get corrected sky value
:50# | @ | Get if GPS using truncated co-ordinates
:51# | m | Get k1 cloud model value
:52# | n | Get k2 cloud model value
:53# | o | Get k3 cloud model value
:54# | p | Get k4 cloud model value
:55# | q | Get k5 cloud model value
:56# | r | Get k6 cloud model value
:57# | s | Get k7 cloud model value
:58# | v | Get tempclear
:59# | w | Get tempovercast
:60# | x | Get cloudflagpercent
:61xx# | | Set k1 cloud model value
:62xx# | | Set k2 cloud model value
:63xx# | | Set k3 cloud model value
:64xx# | | Set k4 cloud model value
:65xx# | | Set k5 cloud model value
:66xx# | | Set k6 cloud model value
:67xx# | | Set k7 cloud model value
:68xx# | | Set temp clear (-8.0)
:69xx# | | Set tempovercast (0.0)
:70xx# | | Set cloudflagpercent (30.0)
:71# | Q | Get MAC Address
:72# | T | Get RTC date/time string dd/mm/yr,hh:mm:ss]
:73# | Y | Get Wind Chill Factor
:74# | b | Get NTP UTC date/time string [dd/mm/yr,hh:mm:ss]
:75# | y | Get NTP LOC [UTC adj by TZ] date/time string [dd/mm/yr,hh:mm:ss]
:76#
:77# | 0 | Get NTP servername
:78# | 1 | Get page display option [String]
:79xxx# | | Set page display option [String]
:80# | 2xxxx# | Get page display time [unsigned int]
:81xxx# | | Set page display time [unsigned int 2000-10000] in milliseconds
:82# | | Sync Rain Bucket Gauge min/hour to rtc
:83# | 4String# | Get MQTT broker IP address
:84String# | Set MQTT broker IP address
:85String# | Set NTP Servername
:86# | 5 | Get average windspeed last 30s
:87# | z | Get maximum wind speed gust last 30s
:88# | 6xx# | Get NTP minutes interval between RTC is synced to NTP
:89xx# | | Set minutes between syncing RTC to NTP
:90# | 7x# | Get SYNC RTC to NTP, if NTP should sync date/time to RTC
:91x# | | Set SYNC RTC to NTP if NTP should sync NTP date/time to RTC
:92x# | | Set GPS truncated [0=No 1=Yes]
:93#

:94String# | Set RTC date/time mm,dd,yyyy,hr,mn,ss
:95# | *x# | Get webserver state (0=Stopped 1=Running)
:96x# | | Start/Stop webserver (0=stop> 1=start)
:97# | !String# | Get MQTT Publish Topic
:98String# | Set MQTT Publish Topic
:99String# | Set NTP time zone
:A0# | ^ | Get make hay
:A1# | [ | Get GPS Static Latitude setting
:A2# | ] | Get GPS Static Longitude setting
:A3x# | | Set GPS Static Latitude setting
:A4x# | | Set GPS Static Longitude setting
:A5# | <String# | Get MQTT Publish Interval
:A6String# | Set MQTT Publish Interval
:A7# | $ | Get BME280 defined altitude (in meters, in place of gps_altitude)
:A8x.xx# | Set BME280 defined altitude (in meters)
:A9# | > | Get BME280 Pressure adjusted to sea-level

### WEBSERVER JSON SUPPORT

There is significant JSON support built into the web server functionality.

HOME PAGE SUPPORT FOR BOTH HTML AND JSON
The home page of the web server can be sent in either HTML format or in JSON format. The admin page responsible for this is /admin2

In the screenshot, the current format setting for the home page is HTML (the current format state is shown between [].

The button shows what the home page format state will change to when clicked by the user.

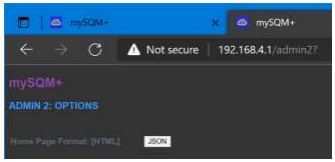
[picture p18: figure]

Clicking on the JSON button will change the home page format to JSON, and any request for the home page will be sent a JSON string.


This can be useful if you want to write your own applications to communicate with the controller. The client application is responsible for connecting to the controller and sending a GET root page / request to the webserver via HTTP.

All parameters are lowercase and values are returned in CELSIUS and METRIC. The client application is responsible for converting any values to FAHRENHEIHT or IMPERIAL units of measurement.

This call obeys the rules for truncate gps and static gps. The gps co-ordinates are derived from the static gps co-ordinates, use static gps is enabled, and truncate gps is enabled on the webserver admin page /admin2

Using the Home Page customizations, you can decide what values/settings appear on the webserver’s Home Page, for both HTML and JSON formats.

JSON SUPPORT FOR CLIENT APPLICATIONS
Client applications can establish a web connection on port 80 to the controller. Using this port, the application can request the groups of data corresponding to various functions of the controller. A request will return a JSON formatted string.

/about REQUEST
An application sending a request /about to the controller will get a JSON string response of the controller details.

{ "product":"mySQM+","Author":"R. Brown, 2020-2021.","ver":"120" }

/d1 REQUEST
An application sending a request /d1 to the controller will get a JSON string response of the “DARKSKY” variables.

{ "sqm":25.08356,"nelm":7.536,"lux":0.00,"skystate":1,"cloudcover":100.00 }

/date REQUEST
An application sending a request /date to the controller will get a JSON string response for the local date and time. Which date and time is sent to the client is subject to the LOCALDATETIMESOURCE on the /admin web page.

{ "local":"02/12/2021,21:28:35","source":rtc" }

/g1 REQUEST
An application sending a request /g1 to the controller will get a JSON string response of the “GPS” variables. This call obeys the rules for truncate gps and static gps.

{ "gpsdate":"01/01/1900","gpstime":"00:00:00","gpslat":"00 00.000000 N","gpslon":"00 00.000000 E","gpsalt":0, "gpssat":0,"gpsfix":0 }

/mac REQUEST
An application sending a request /mac to the controller will get a JSON string response of the MAC address value.

{ "mac":"24:62:AB:B0:8C:DC" }

/makehay REQUEST
An application sending a request /makehay to the controller will get a JSON string response of the vpd value (make hay < 10 is good) value.

{ "makehay":7.12 }

/mqtt REQUEST
An application sending a request /mqtt to the controller will get a JSON string response of the MQTT broker IP and connection details [if enabled].

{
"brokerip":"192.168.2.129","publishtopic":"mySQM/rufus","subscribetopic":"mySQM/cmdset",”mqrrp ubtime”:30,"mqttconnectstate":"UNKNOWN","mqttclientstate":"false" }

/ntp REQUEST
An application sending a request /ntp to the controller will get a JSON string response of the NTP local date and time dynamic values [if enabled].

{
"ntpldate":"","ntpltime":"","ntpudate":"","ntputime":"","ntpserver":"pool.ntp.org","ntptz":"TZ_Asia_K uaka_Lumpur","ntptz": “<+08>-8” ,"rtcsyncntp":0,"rtcsynctime":30 }

/rain REQUEST
An application sending a request /rain to the controller will get a JSON string response of the rain information [if enabled].

{
"raining":0, "rvout":2.16,"raincurrhour":0.00,"rainprevhour":0.00, "raincurrday":0.00,"rainprevday":0.00
}

/rd REQUEST
An application sending a request /rd to the controller will get a JSON string response of all dynamic values except GPS.

{
"sqm":12.21815,"nelm":-1.461,"ambient":20.000,"humidity":50.0,"dewpoint":9.269, "pressure":1100.00,"skyambient":20.000,"skyobject":20.000,"lux":1.40011,"skystate":0, "cloudcover":0.00,"raining":0,"rvout":0.00,"windspd":0.00,"beaufort":0,"winddir":0
}

/rtc REQUEST
An application sending a request /rtc to the controller will get a JSON string response of the Real Time Clock dynamic values [if enabled].

{ "rtcdate":"19/07/2021","rtctime":"18:16:23" }

/t1 REQUEST
An application sending a request /t1 to the controller will get a JSON string response of the “TEMPERATURE” variables.

{ "ambient":20.000,"dewpoint":9.269,"skyambient":23.850,"skyobject":23.690 }

/tlscf REQUEST
An application sending a request /tlscf to the controller will get a JSON string response of the TLSCorrectionFactor variable.

{ "tlscf":1.8 }

/uptime REQUEST
An application sending a request /uptime to the controller will get a JSON string response of the system uptime.

{ "uptime":"00:00:06" }

/w1 REQUEST
An application sending a request /w1 to the controller will get a JSON string response of the “WEATHER” variables.

{ "humidity":50.0,"pressure":110000.00,"raining":0,"rvout":0.00,"raincurrhour":0.00, "raincurrday":0.00,"windspd":0.00,"beaufort":0,"winddir":0 }

### WEBSERVER SERVICE MANAGEMENT SUPPORT

Additional administration requests are available. These are shown below.

/rebootws REQUEST
An application sending a request /rebootws to the controller will cause the controller to stop and then restart the web-server service.

/reboottcp REQUEST
An application sending a request /reboottcp to the controller will cause the controller to stop and then restart the TCP/IP-server service [used by TCP/IP applications in Windows and LINUX on port 2121].

/reboot REQUEST
An application sending a request /reboot to the controller will cause the controller to reboot. There is no response to this request.

/rbgsync REQUEST
An application sending a request /rbgsync to the controller will cause the controller to update the minute and hour values used by the Rain Bucket Gauge to that of the Real Time Clock. There is no response to this request.

### WEBSERVER XHTML SUPPORT

The webserver supports direct XJTL requests, where the value of the requested item is returned. The home page of the webserver as an HTML page has embedded scripts in the page that send XHTML requests to the server, and the responses are used to dynamically update the web page contents.

This means that you do not need to use REFRESH to get an updated page with new values, because the home page does this dynamically without having to request the home page again.

XHTML Request | Value returned
/ba | ambient
/bh | humidity
/bd | dewpoint
/bp | pressure
/ma | skyambient
/mo | skyobject
/sq | sqm
/ne | nelm
/lu | lux
/ss | skystate
/cc | cloudcover
/ra | raining
/rv | rvout
/rh | raincuurhr
/ry | raincurrday
/ws | windspd
/bs | beaufort
/wd | winddir
/wc | windchill
/ut | system_up_time
/mh | makehay

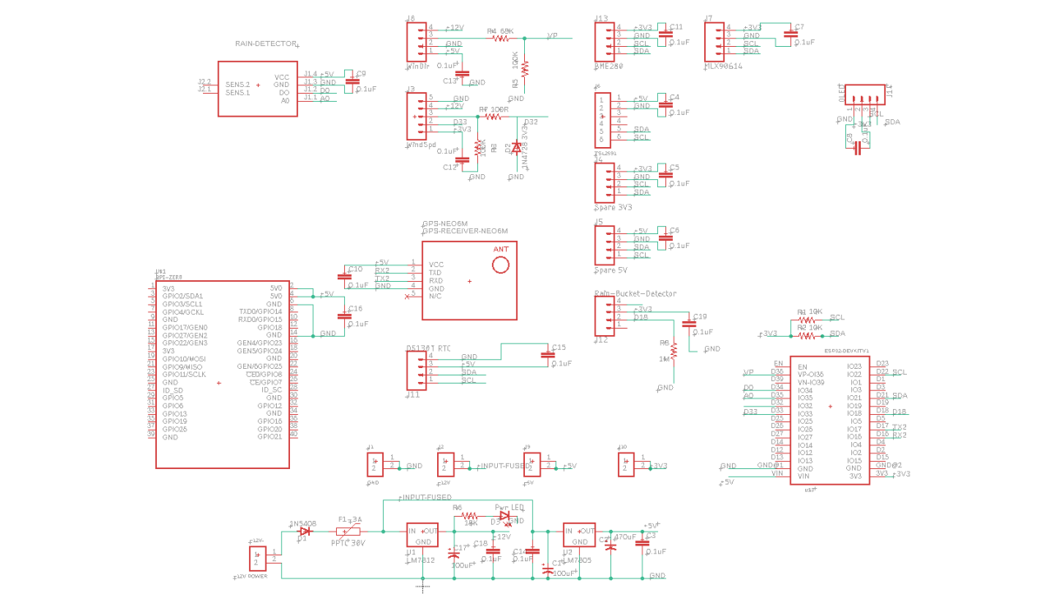
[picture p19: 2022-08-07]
PCB-Petes-ESP32-PiZero/Schematic V9.png

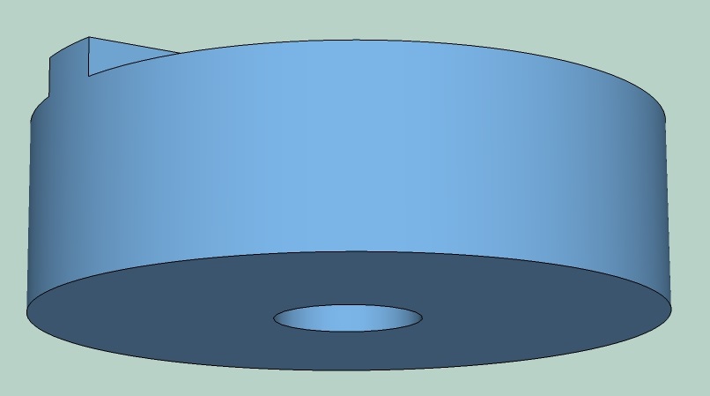
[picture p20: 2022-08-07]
Wind Direction Sensor/WINDDIRECTION3DPRINT/Design/LeverArmFinal.jpg

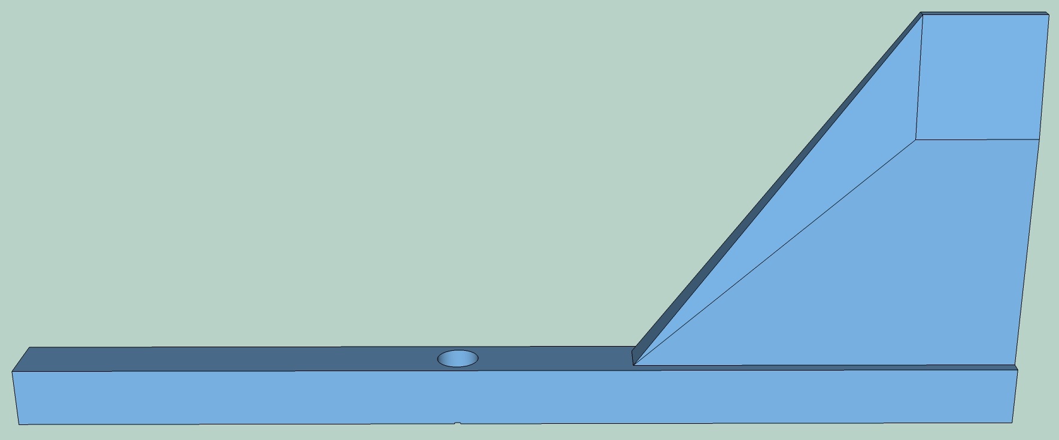
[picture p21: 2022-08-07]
Wind Direction Sensor/WINDDIRECTION3DPRINT/Design/WindPointerFinal-2.jpg

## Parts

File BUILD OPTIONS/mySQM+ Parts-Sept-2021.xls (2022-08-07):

 | mySQM+ Rev11 PCB Parts List | Quantity
 | Arduino Header Pins 40, Breakable 2.54mm 1pc of 40 pins | 1 | 0.99
 | mySQMPRO2 ESP32 PCB | 1 | 4.99
IC1 | ESP32 -WROOM-32-Expressif-ESP-32-ioT chip Development Board | 1 | 5.20
IC1-A, IC1-B | 15P Headers for ESP32 2.54mm | 2 | 1.73
IC2 | LM7805 Voltage Regulator TO-220 package | 1 | 0.99
IC2 | TO-220 Heat sink + screw 20*15*10 | 1 | 1.44
C2 | 0.1uF Ceramic capacitor | 1 | 0.99
C1 | 0.33uF Ceramic capacitor | 1 | 0.99
C3 | 470uF 35V Capacitor bipolar | 1 | 0.99
C4, C6 | 100nf Ceramic Cacpacitor | 1 | 0.99
C5 | 100uF 35V Bipolar Capacitor | 1 | 0.99
R1,R2 | Resistors 10KΩ 1/4 watt | 2 | 0.99
D1 | 1N5408 3A Diode | 1 | 1.62
J3 | PTC Polymer Resettable Fuse 3A | 1 | 3.72
J4 | 12V Prewired LED Red 3mm with Bezel | 1 | 2.76
J2 | On/Off toggle switch (power) | 1 | 2.66
J1 | Power Socket Female Panel Mount 12V 2.1mm x 5.5mm | 1 | 1.67
J1 | Power Plug Male 2.1mm x 5.5mm | 1 | 0.99
 | 2m cable for 12V power 2 core 3A Black/Red | 1 | 0.99
 | 3D Printed Case | 1
 | M2 x 10mm Pan head srew [case lid] | 4 | 0.99
 | M2 x 5mm Pan head stainless steel screw philips [secure PCB] | 4 | 0.99
 | TSL2591 Sensor
J9 | TSL2591 Sensor | 1 | 5.99
 | RAIN Sensor
J5 | Rain Sensor | 1 | 0.99
 | MLX90614 IR Sensor
J7 | MLX90614 IR Sensor | 1 | 4.04
 | BME280 Barometric Sensor
J8 | BME280 Barometric Sensor | 1 | 3.59
J10 | GPS NEO-6M
 | GY-NEO6MV GPS Module | 1 | 4.99
 | DISPLAY
J6 | OLED 0.96" I2C Display | 1 | 2.85
 | 4P to 4P XH2.54mm straight cable for connecting OLED | 1 | 0.99
 | Anenometer
J11 | Adafruit Anenometer | 1 | 44.95
 | QS-FS 0.4/2V
R3 | Resistor 10KΩ 1/4 watt | 1 | 0.10
D2 | Zener Diode 1N4728A 3V3 | 1 | 1.35
 | Wind Direction
J12 | Analog Wind Direction Sensor 0-5V | 1 | 38.99
R4 | Resistor 68KΩ 1/4 watt | 1 | 0.10
R5 | Resistor 100KΩ 1/4 watt | 1 | 0.10
 | Rain Bucket Gauge
J17 | Sparkfun SEN-08942 | 1 | 64.99 | Includes Anemometer and Wind Direction Vane
R6 | Resistor 10KΩ 1/4 watt | 1 | 0.1
 | MISC
 | Case to hold MLX90614 - remove existing AM2320B SH21 Sensor | 1 | 2.56
 | Plastic lens assembly clear 8mm x 8mm 90 degree - cover for TSL2591 Sensor | 1 | 2.52
 | M2 x 6mm pan head bolt - to secure Rain Sensor | 4 | 0.10
 | No power supply
 | No USB cable
 | Consider using round microscope glass slide cover about 10-12mm??
 | Can get 8mm x 8mm , recess square by 1mm into lid

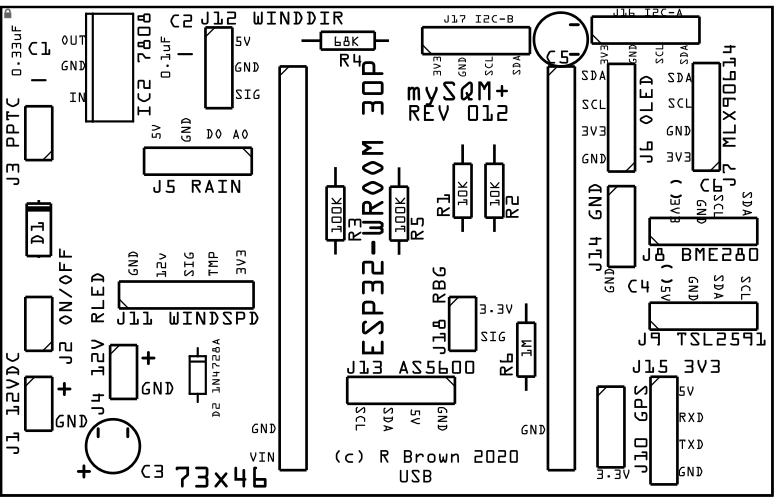
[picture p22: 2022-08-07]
BUILD OPTIONS/ESP32/mySQM+ 012_Parts_Layout.png

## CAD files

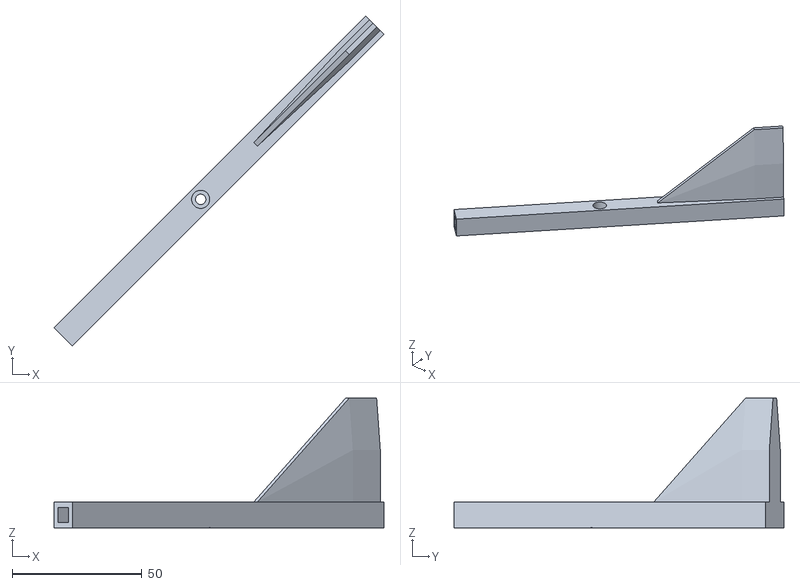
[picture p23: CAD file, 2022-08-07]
Wind Direction Sensor/WINDDIRECTION3DPRINT/Design/WindPointerFinal-1.stl
127.3 x 127.3 x 50.0

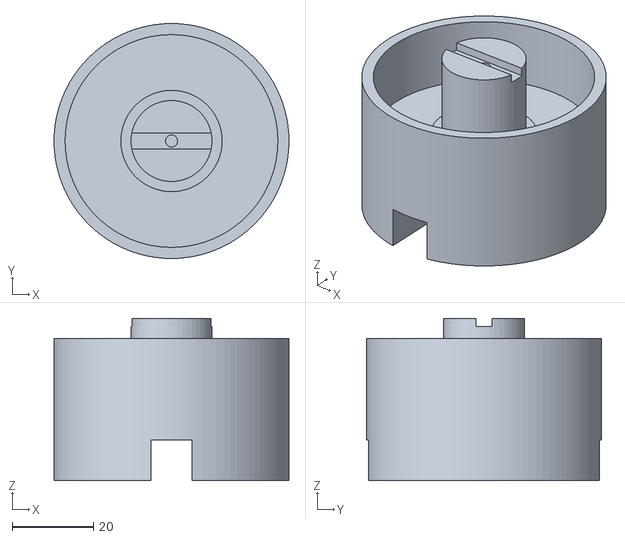
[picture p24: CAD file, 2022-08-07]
Wind Direction Sensor/WINDDIRECTION3DPRINT/Design/CoverFinal.stl
58.0 x 58.0 x 40.0

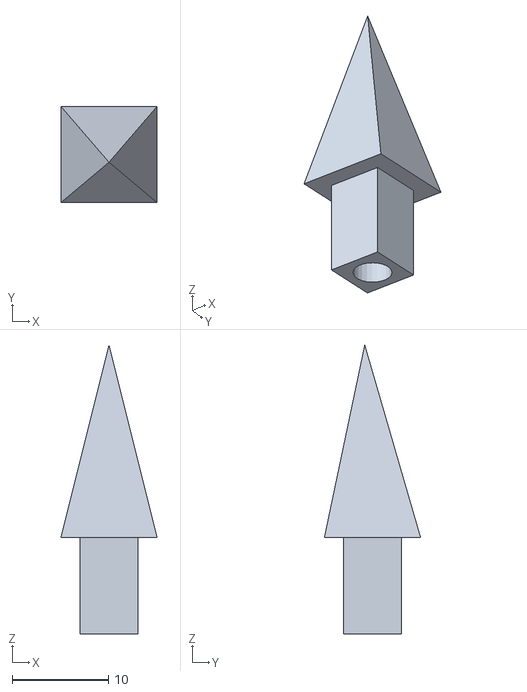
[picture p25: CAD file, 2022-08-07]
Wind Direction Sensor/WINDDIRECTION3DPRINT/Design/WindPointerTipFinal.stl
10.00 x 10.0 x 30.0

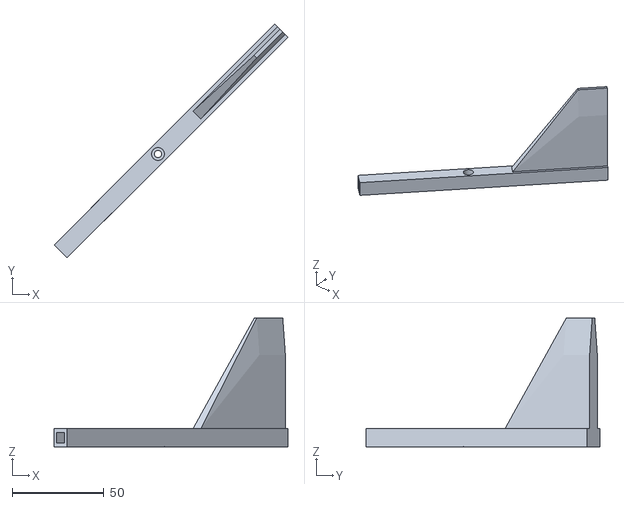
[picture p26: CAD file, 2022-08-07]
Wind Direction Sensor/WINDDIRECTION3DPRINT/Design/WindPointerFinal-2.stl
127.3 x 127.3 x 70.0

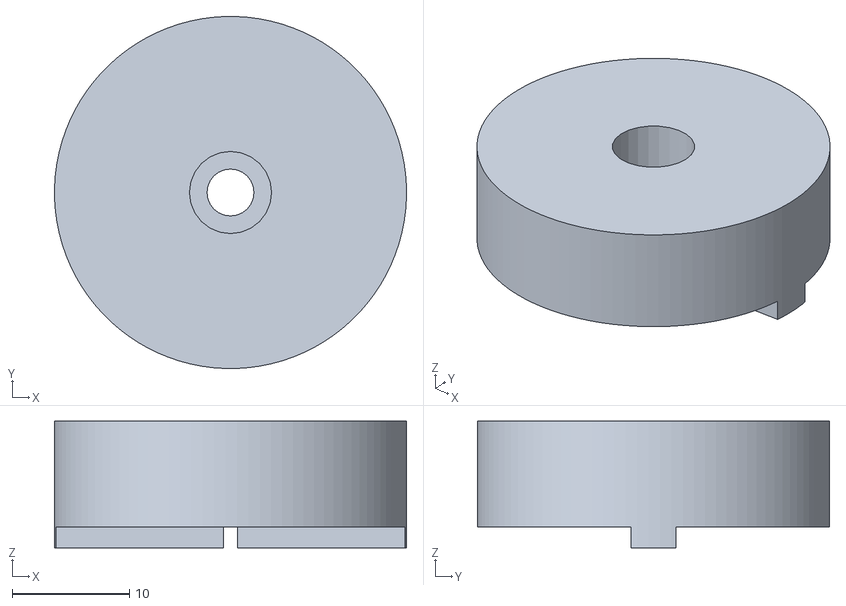
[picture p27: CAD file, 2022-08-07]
Wind Direction Sensor/WINDDIRECTION3DPRINT/Design/LeverArmFinal.stl
30.0 x 30.0 x 10.8

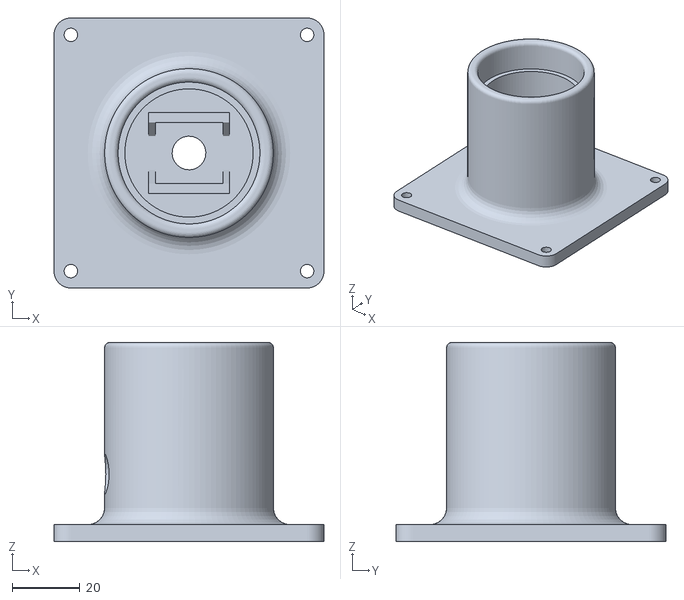
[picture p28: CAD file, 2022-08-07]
Wind Direction Sensor/WINDDIRECTION3DPRINT/Design/BaseFinal-repaired.stl
80.0 x 80.0 x 59.0

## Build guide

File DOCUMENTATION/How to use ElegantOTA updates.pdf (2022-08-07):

1 | P a g e

# How to use ElegantOTA updates

Paul P.
Nov 2021

OTA updates work with ACCESSPOINT and STATIONMODE. Make sure that you have installed the Library for ElegantOTA before proceeding.

### 1: SET CONTROLLER MODE

First, you need to enable the controller mode in Section 8 of the controllerconfig.h file. In the example below, STATIONMODE is selected. In Section 8 of the file, enable STATIONMODE

// to work as a station accessing an existing AP, define stationmode,
// uncomment next line
#define STATIONMODE 3

### 2: SET OTA METHOD

In Section 11, select the OTA method as UseElegantOTA

// ====================================================================== // 11: OTAUPDATES (OVER THE AIR UPDATE) NAME AND PASSWORD CONFIGURATION // ====================================================================== // Select ONE of the following choices for OTA
// If not using OTA then leave as commented and go to the next section

// To use the ArduinoOTA code, uncomment the next line
//#define OTAUPDATES | UseArduinoOTA

// To use theElegantOTA code, uncomment the next line
#define OTAUPDATES | UseElegantOTA

### 3: SET AUTHENTICATION CREDENTIALS

Take a note of the authentication credentials and change them if necessary (OTAName and OTAPassword)

#if (OTAUPDATES == UseElegantOTA) | // For the ElegantOTA service

const char *OTAName = "mysqmesp"; | // the username and password for the
ElegantOTA service
const char *OTAPassword = "mysqmesp"; | // use lowercase only for the password
#endif // #if defined(ElegantOTAupdates)

### 4: PROGRAM THE CONTROLLER

Compile and flash the firmware.

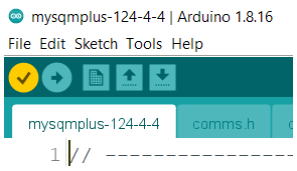
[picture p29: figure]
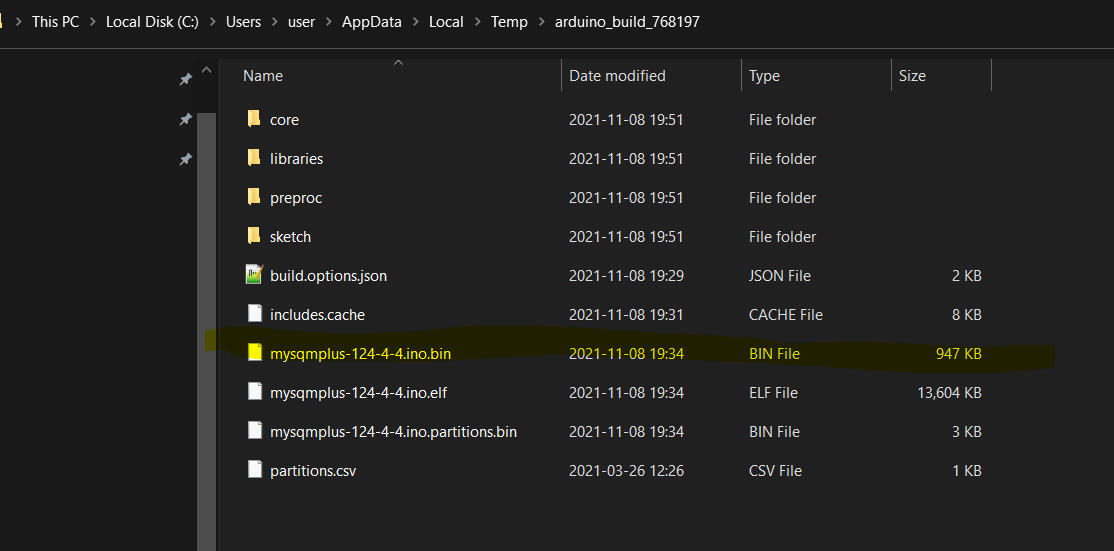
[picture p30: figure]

2 | P a g e

### 5: USING OTA

After the update, future updates can be done in a web-browser. How-ever, you can only upload bin files, and are generated using the Arduino IDE.

### 5.1 VERIFY THE CODE

Use Arduino IDE to compile the new code (CTRL-R). This creates the special files that are needed for OTA uploads.

### 5.2 FIND THE LOCATION OF THE CONTROLLER BIN FILE

When the Arduino IDE has finished compiling the sketch, find the folder where the build files were created, usually it's in the line above “Sketch uses” as illustrated below

C:\\Users\\paul\\AppData\\Local\\Arduino15\\packages\\esp32\\tools\\xtensa-esp32-elf-gcc\\1.22.0-97-gc752ad5-5.2.0/bin/xtensa-esp32-elf-size"
-A "C:\\Users\\user\\AppData\\Local\\Temp\\arduino_build_XXXXXX/mysqmplus-124-4-4.ino.elf
"Sketch uses xxx bytes (yy%) of program storage space. Maximum is ..." in the status window:

Copy the highlighted part, open file-explorer, paste it in the address bar of the Explorer Window (replacing \\ with a single \ ) and press enter.

The binary firmware file is the mysqmplus-xxx.ino.bin file.

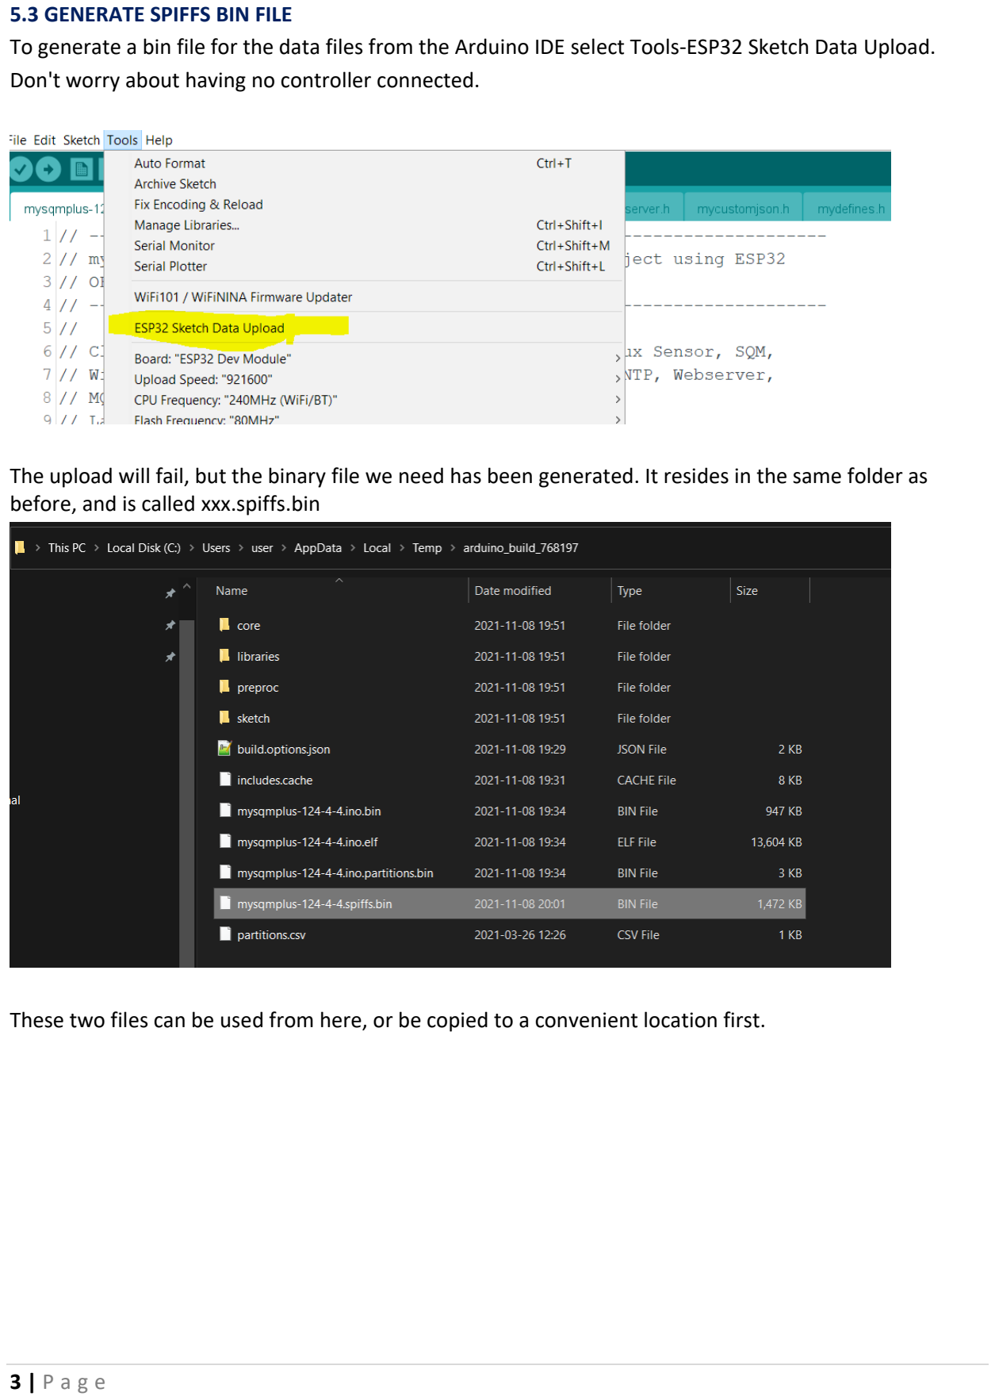
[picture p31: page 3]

3 | P a g e

### 5.3 GENERATE SPIFFS BIN FILE

To generate a bin file for the data files from the Arduino IDE select Tools-ESP32 Sketch Data Upload. Don't worry about having no controller connected.

The upload will fail, but the binary file we need has been generated. It resides in the same folder as before, and is called xxx.spiffs.bin

These two files can be used from here, or be copied to a convenient location first.

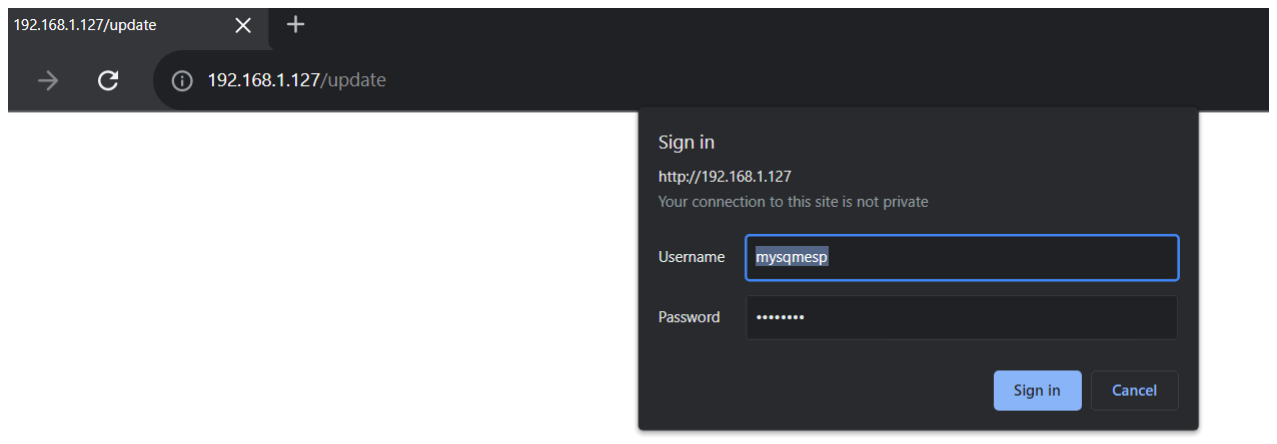
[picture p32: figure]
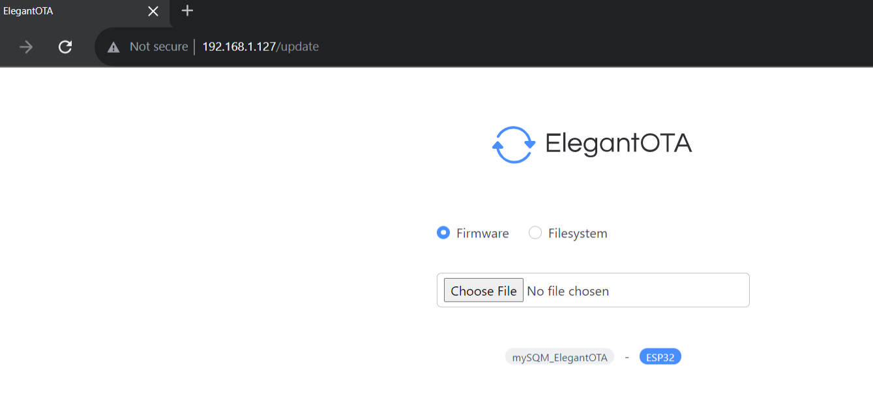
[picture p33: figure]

4 | P a g e

### 6: UPDATING CONTROLLER CODE AND SKETCH DATA FILES USING OTA

### 6.1 CONNECT TO THE OTA UPDATE PAGE

To upload the files to the controller (which is running), open a web-browser type in the following URL (change 192.168.1.127 to the address of your mySQM+ controller and enter the required credentials).

http:// 192.168.1.127/update

### 6.2 THE OTA UPDATE PAGE

After signing in to the OTA service. the home page for updating is shown (screenshot below)

### 6.3 UPLOAD THE NEW CONTROLLER FIRMWARE CODE

Select Firmware, then Choose File. Navigate to the folder where the mysqmplus---.ino.bin file was found, select the file and the upload will start.

When the upload is finished, click back (in the web-browser), wait a few seconds for the controller to reboot.

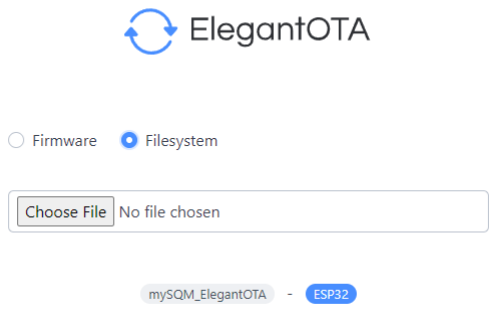
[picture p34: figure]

5 | P a g e

### 6.4 UPLOAD THE NEW CONTROLLER SPIFFS SKETCH DATA FILES

You may need to reconnect to the OTA update page (see 6.1)

Select Filesystem. then Choose File. Navigate to the folder where the mysqmplus---spiffs.bin file was located, select the file and the upload will start.

That's all...
Also check out the video!

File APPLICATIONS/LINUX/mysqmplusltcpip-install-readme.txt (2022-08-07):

==================================================================================
mySQMPLUSL TCPIP Linux Application for mySQM+ controllers (TCP/IP)
(c) Robert Brown 2019-2022. All rights reserved.
==================================================================================

==================================================================================
USING mySQM+ CONTROLLERS WITH LINUX
==================================================================================
There are a number of ways you can use a mySQM+ Weather Controller with Linux systems.

1. This Linux application 
2. mySQM+controller configured for TCP/IP ACCESSPOINT or STATIONMODE
or

mySQMPLUSLTCPIP LINUX APPLICATION
The provided LINUX application was developed and tested on UBUNTU with the MATE desktop environment, and supports TCP/IP connections to a mySQM+ controller.

After recompiling the source code, copy the recompiled executable file mysqmplusltcpip AND mysqmplusltcpip.ini files to a user folder on your Linux system (like a folder under the desktop)

mysqmplusltcpip.ini SETTINGS INI FILE
This file is used to save and restore the application settings.

CHANGE CONTROLLER IP ADDRESS SETTINGS IN THE mysqmplusltcpip.ini .ini FILE
The INI file will need changing. There is a string for the variable ipaddr which looks like

ipaddr=192.168.4.1

You will need to change the ipaddr string to what is used for your system.

CHANGE LOG FILE LOCATION SETTINGS IN THE mysqmplusltcpip.ini FILE
The mysqmplusltcpip.ini file will need changing. There is a string for the variable logfilepath which looks like

logfilepath=

You will need to specify the path where your log files will be stored. The path below points to user bob’s home folder, and there is a folder on bob’s desktop called myLogFiles

logfilepath=/home/bob/Desktop/myLogFiles

After making the required changes to the mysqmplusltcpip.ini file, save the file.

Alternatively, when the application runs the first time, it will detect that the logfile path has not been specified in the INI file and ask you to specify the folder where the log files can be saved. Once this is specified, then the log path is saved for future use.

REQUIRED GROUP PERMISSION
You must be a member of the group tty (Ubuntu-Mate) (others are the dialout group)
Use menu, administration, users and groups, manage groups, tty, properties
and ensure that your name is checked, then click OK

FLAG APPLICATION AS EXECUTABLE
Run a terminal window (as root) in the folder and change permissions of file

chmod +x mysqmplusltcpip

or you can right mouse click the file, properties, permissions and check allow 
executing file as program.

OTHER LINUX SYSTEMS
You will need to recompile the source code using Lazarus Pascal, in order to run the application on a different Linux system (or Raspberry Pi).

INSTALL THE ARDUINO IDE
To install the Arduino IDE so you can program the controller, open a terminal window and type the following commands

sudo apt-get update
sudo apt-get install Arduino

INSTALL LAZARUS
If you need to recompile the source code, you will need to install Lazarus

sudo apt-get update
sudo apt-get upgrade
sudo apt-get install fpc
sudo apt-get install Lazarus

RE-COMPILING THE SOURCE
To recompile the source, download the source files and extract the zip file into a folder. In that folder, open the mysqmplusl.lpi file in Lazarus and then from the menu bar select Run-Compile. Once the program is built, the mysqmplusltcpip file can be executed.

When the program is first executed, and you did not specify where the log files are to saved, the application will first ask where to save the log files. After selecting a folder location, the application will save the log file path and continue.

PLEASE READ THE DOCUMENTS FOR MORE INFORMATION
The documents are located in the Zip file under the Documents folder.

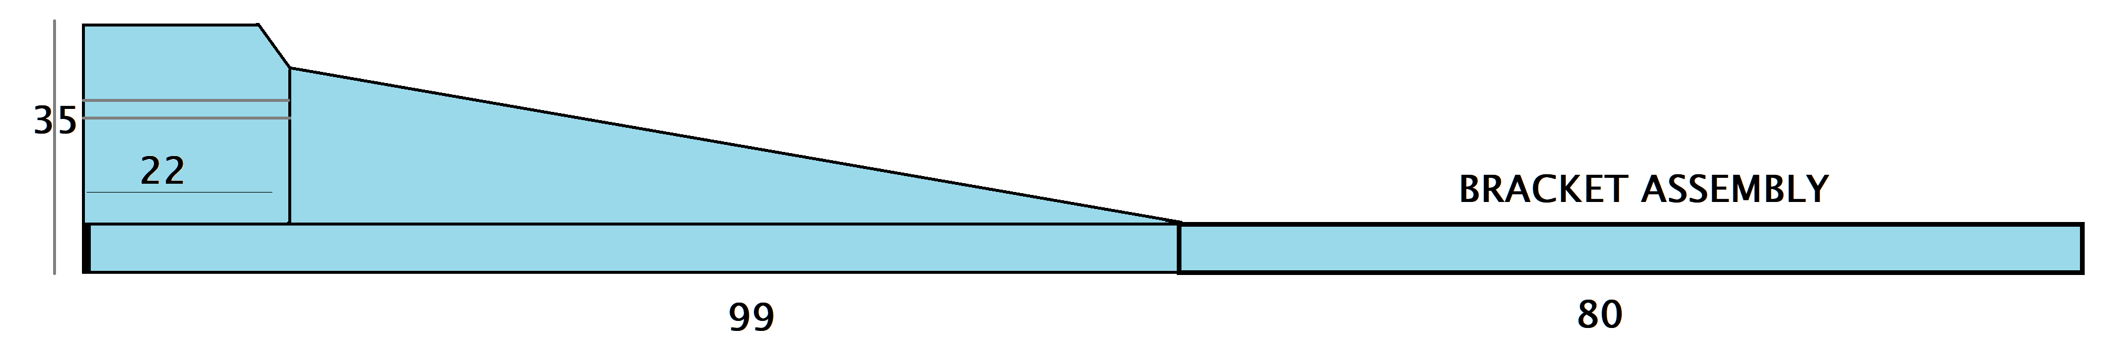
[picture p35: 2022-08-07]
Wind Direction Sensor/WINDDIRECTION3DPRINT/Mounting-Bracket-Assembly.png

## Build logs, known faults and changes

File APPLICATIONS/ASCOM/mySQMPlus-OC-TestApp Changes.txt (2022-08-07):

mySQMOCTestApp :Observing Condition Test Application

(c) R Brown, 2020-2021
All rights reserved

1_0_0_13
Fixes to work with mySQM+ ASCOM OC driver v014 and higher

1_0_0_12
Fix for exception handling returned from ASCOM OC Driver
Rename application

1_0_0_11
Fix for SkyTemperature not being retrieved when connecting

1_0_0_10
Add clear all and get all buttons

1_0_0_9
Update GUI
Fixes for disconnection, connection, TCP/IP and USB Serial
Add Rainrate
Show data parameters when retrieved
Add clear timer to Status field
Add connection status 

107
Give indication of when connected

106 
Add windspeed, wind direction, cloudcover

104 11122017
Small changes to interface

103 28102017
Change certificate signing to 2022

102 25102017
Prevent form from being resized

101 25102017
Add version number to title bar of window

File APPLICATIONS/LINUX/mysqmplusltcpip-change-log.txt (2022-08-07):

==================================================================================
mySQMPUSL TCP/IP Linux Application for mySQM+ controllers
(c) Robert Brown 2020-2022. All rights reserved.
==================================================================================

==================================================================================
CHANGE LOG
==================================================================================
Major Version	1
Minor version	1
Revision 		1
Build 			8

1.1.1.8
SERVICES
Add new Services tab and link into background load
Add get button to get and display controller services
Add port settings for Management and Web servers 
Add Get status/Start/Stop Management Server to menu

INTERFACE
Add new Interface tab
Add Background Load groups to Interface tab
Move buttons Temp/Distance to Interface tab
Move buttons Static, reboot to Interface tab
Move Background Load Timer checkbox to Interface tab

TSL2591
Add new TSL2591 tab and link into background load
Add TSL2591 Sample Size Get/Set
Add TSL2591 Averaging Get/Set
Add TSL2591 Properties tslsamplesize and tslaveraging to INI file
Add TSL2591 checkbox to connection tab, send on connect
Add TSL2591 to background load timer
Add shortcut key ALT+T for TSL2591 tab
Move tsl correction factor to TSL2591 tab 

BME280
Add Sea level pressure, BME280 Altitude, backgroud load services to INI file
Add sl-pressure and bme280 altitude to custom log file and data log file
Add sl-pressure and bme280 altitude to Get All button and Get button on BME280 tab
Update Get/Set buttons on BME280 tab to add altitude/pressure-adj

NTP
Add ntpUdate interval (15m to 60mm), default is 30m
Add restart button on NTP tab (for next release)
Remove sync rtc to ntp interval 

MQTT
Add MQTT start stop buttons 
Add MQTT status 
Add MQTT Subscribe enable to MQTT tab, save/restore state from INI file
Update code for MQTT Get and Set buttons

WIND
Add sensor names to Wind tab

GPS
Add gps fix indicators to GPS tab

CUSTOM LOGGING
Add custom logging option for SL-pressure and BME280 Altitude
Move custom logging options from logging tab to custom logging tab

GENERAL
Add Save/restore temp mode and distance mode from INI file
Add Background Load Groups Display, GPS, MQTT, NTP, RTC, Cloud Model, TSL2591
Add Send on Connect Display, Distance mode, GPS, NTP, Sky-Model, Temp Mode, TSL2591
Change tab order to match Windows application
Change order of pages on Display tab to match new firmware 128-27
Fix for background load issues (some pages not loading due to INI file errors)

1.1.1.6
Add beaufort to wind tab
Add make hay to bme280 tab
Add send on connect NTP settings on connection tab
Add background load timer and enable box on connection tab
Add fields for day/month/year/hour/minute/second on rtc tab
Add set button on rtc tab to update controller settings
Add Set RTC to PC Date-Time to RTC tab
Add system date/time string to RTC tab
Add wind speed average 30s to Wind tab
Add wind speed max gust 30s to Wind tab
Add windavg, windgust, Beaufort, Make hay to custom logging tab
Add timezone string to ntp tab
Add set button on ntp tab to update controller settings
Add Sync RTC to NTP state on NTP tab
Add Sync RTC to NTP Time Interval on NTP tab
Add windavg, windgust, beaufort,make hay. macaddr to data logging
Add get windavg, windgust, beaufort to get wind values
Add new checkboxes to INI file so they are saved/restored
Add system uptime to connection tab
Add system uptime to data log
Add system uptime to refresh timer interval
Add k1-k7, tc, toc, cfp to Sky cloud model tab
Add set button to Sky Cloud model tab
Add k1-k7, tc, toc, cfp to INI file
Add checkboxes for page display option rather than string of 0 and 1
Add page descriptions for each page on display tab
Move custom log enable/overwrite and custom log filename to logging tab
Fix for NTP set causing controller reboot
Fix for MQTT set causing controller reboot

1.1.1.5
Fix log timer interval code to ensure log interval times are set correctly
Add webserver get status, webserver start/stop service to Menu bar
Add Connect and Disconnect links on Menu bar
Add Compass direction text on Wind tab
Add new [user specified] custom log filename on Custom Logging tab
Add command line arguments processing - allows OS to start application, connect, arg = --auto and start logging without user intervention
Add auto start options on Connection tab
Add auto reconnect timer and interval on Connection tab
Add shortcut keys for NTP tab (ALT+N) and the MQTT tab (ALT+Q)
Fix for unable to edit/change page display option string on Display tab

1.1.1.4
Fix for custom logging winddirection
Fix for log data file incorrect json string for rainfallcurrentday
Fix for Display Page Option unable to edit
Remove a comma in JSON logs being added before closing brace }
Remove Log Data - Log as JSON is default
Remove Log Custom Log as DATA, JSON is default
Remove MQTT as JSON, JSON is default
Remove GPS Format option
Remove from ini and support code, gpsformat,mqttsendjson,logcustomasjson,logdataasjson
Remove comment line from start of data log file
Add static latitude and longitude felds to gps tab
Add support code to handle static latitude and longitude get/set buttons
Add MQTT publish interval field to MQTT tab and add support code
Add windchill checkbox to Custom Logging tab
Add windchill to logging data and custom logging
Changes to logdatafile and logcustomdata 
Changes to logfiles to ensure keynames match pdf 018 protocol

1.1.1.3
Fix for gps static state not saving/restoring correctly

1.1.1.2
Add menu item INI submenus read and save for testing purposes]
Add custom log tab and custom logging
Add additional log messages and status messages
Add after connect, set tab to Main tab
Add after disconnect, set tab to Connection tab
Add Versioning information
Add Version menu item (version now automatic)
Add Clear and set buttons to clear/set custom log values 
Add additional hints for form elements
Add Send 'GPS settings' to Send On Connect choices
Add ALT-Z to pop-up form listing shortcut keys
Fix for delayonconnecttime
Fix for skystate
Fix for set folder - rewrite code
Fix for MAC address showing leading Q in response
Fix for bug in get mlx90614 skystate
Fix for get display enabled state
Fix for get mlx90614 object
Fix for sky ambient conversion error in log timer
Fix for rainfallcurrenthour conversion error in Connect
Fix for log file data being cached (data was not being fully written to file)
Fix for log filenames in setfolderbtn (change from mysqmpro to mysqmplus)
Fix for ambient, humdity, dewpoint, sky ambient, sky object, rvout, cloud cover percent
    windspeed, wind chill factor and rainfall to show two decimal places
Fix for main tab value of bme280 ambient temperature not showing Fahrenheit values
Fix for log files not showing decimal places for windspeed, rainfall, 
Fix in log data file for rainfall values shown incorrectly when JSON is selected
Fix for custom log file not logging values with decimal places
Fix for custom log file not logging cloudcover percent correctly
Fix for GetAll not showing decimal places for some values
Fix for Get on SkyCloudModel tab not showing skyobject/skyambient values with decimal places
Fix for Get on Rain tab not showing rvout with decimal places
Fix for logdatatofile as JSON writing a closing } twice 
Fix for switching to Main tab when connection fails
Fix for firmware version showing as null in data logs
Fix for } showing at end of custom log when json is not selected
Fix for comma between data and time of cloud sensor II log files
Fix for single quote appearing in custom log files - non json
Fix for gps details not clearing after Disconnect
Rewrite disconnect and exit code
Rewrite file routines - files only created when referenced
Rewrite handling of responses
Rewrite header information for Data log files

1.1.1.1
Add versioning information

019
Rewrite of application

018
Rename units, forms and project name

017
Add error handling for data format conversions
Save/Restore LogData, LogErrors, LogCS2 checkbox states in INI file
Add error handling to file operations
Add autodetect logpath on startup, ask user for location folder to store logfiles

016
Add CSII logfile
Add CSII Settings tab
Add CSII settings to INI file
Add MQTT Settings tab
Add MQTT settings to INI file
Add GPS data to datalog file instead of "" no information
Add header line to datalogfile
Change Logfiles date stamp to yyyy-MM-dd
Move Connected State and Status from Connection Tab to above Status Messages
Rename MLX90614 tab to Cloud Model tab
Remove Lux sensor configuration tab
Remove Lux sensor gain and integration settings from INI file

015
Combine TCP/IP and Serial Interface into single application

014
Wrap firmware calls around firmware file version so application does not hang on older firmware

013
Add OLED tab
Add Rainfall to Rain tab
Add Syn RBG to RTC button on rain tab
Add RTC tab
Add NTP tab
Add Reboot button to Connection tab
Add MAC Address field on Connection tab
Remove graph logo icon
Add Wind Chill Factor to Wind tab
Add Rainfall values to data log file

012
Change header of log files to MYSQMPLUS

011
Convert pressure to double

009
Add datalogfilename, tcp/ip address and refreshtimer interval to INI settings, 
save on exit, reload on start
Add 1m refresh interval to datalog timer
Add label on logging page to indicate refresh timer status

008
Change logfile format CLEAR / CLOUDY to 0 / 1
Check Data log file formatting

007
Fix rvout issue
Fix time stamps on graphs
Add mps field to Rain tab

006
Implement graphs

004 
remove setpoint1/2
add logging
set gps fix checkbox to disabled

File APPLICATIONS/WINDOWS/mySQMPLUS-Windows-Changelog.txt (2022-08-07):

-----------------------------------------------------------------
mySQM+ Windows Application
(c) Robert Brown 2020-2022, All rights reserved.
brown_rb@yahoo.com
-----------------------------------------------------------------

Permission is granted for personal/academic/education use only.

-----------------------------------------------------------------
Change log
-----------------------------------------------------------------

0.0.5.5
Fix for SYNC RBG to RTC text on Rain-Wind tab

0.0.5.4
Change tabular layout (rain-wind and bme-mlx)
main tab has most values
fix error where windspeed value was cleared when wind max gust was updated
fix shortcuts
Change GUID

0.0.5.3
Fix for MQTT Publish interval (MQTT tab, now in seconds)

0.0.5.2
Fix for ntpclient showing incorrect state

0.0.5.1
Add shortcut AT-T for TSL2591 tab

0.0.5.0
CHANGE CLASS ID
OLD GUID 4e9e20cb-9a24-4765-9781-3c00448e0792
NEW GUID cf82bb44-b008-4549-8ae8-bfda7dac0efd
Update support for protocol 031
Remove sync rtc to ntp interval
Add ntpUdate interval range 15m to 60m 1hr, default is 30m - 18000
Add MQTT start stop buttons 
Add MQTT status 
Add MQTT Subscribe enabled state 
Add NTP status to NTP tab
Add new tsl2591 tab 
Move tsl correction factor to tsl2591 tab 
Add TSL2591 Sample Size Get/Set 
Add TSL2591 Averaging Get/Set 
Add Properties tslsamplesize (int 5-100) and tslaveraging (bool) 
Update services tab with support for Management server 
Add Get status/Start/Stop Management Server to menu 
Add Get status/Start/Stop TCPIP Server to menu 
Add restart button on NTP tab 
Add TSL2591 tab to Background Load group on the Interface tab 
Add TSL2591 tab to Send On Connect group on the Interface tab 
Fix error in Web Server and Management Server not starting/stopping 
Fix for MAC address truncated by 1 digit
Fix for NTP Timezone not changing
Fix for Display Option String errors in Set and Get

0.0.4.0 
Changed order of tabs
main, sky cloud model, bme280, rain, wind, gps, mqtt, ntp, rtc, display, services, csii settings,
custom logging, logging, interface, connection
Services tab				  
gps fix indicators			
change TLS to TSL			
Wind speed/direction sensor names   
K1-K7 get/set                       
gps_altitude is now float			
string leading char of response msg changed to $, required by firmware 127-05 

0.0.3.9 
Fix for cloud flag percent sending wrong value in Set button for Sky Cloud Model tab
Add connection tab

0.0.3.8
Add BME280 Altitude
Fix custom logging of bme280alt (wrong value written to logfile)

0.0.3.7
Remove serial interface
Add slpressure

0.0.3.6
Fix for spelling mistake on Display tab

0.0.3.5
Fix for incorrect logging values related to wind speed average and max gust

0.0.3.4
Fix for windir not showing in data logfile
Change JSON keynames to match other logging applications and MQTT by the controller

0.0.3.2
Add windavg to custom logging tab
Add maxgust windspeed to custom logging tab
Add windavg/maxgust to json log file
Add windavg/windgust to clearall and setall buttons on custom logging tab

0.0.3.1
[Only use on firmware 125-60 or higher]
Add windavg to Wind tab
Add maxgust to Wind tab
Add windavg and maxgustto wind graph on wind tab
Add windavg and maxgust to json log file
Remove firmware version check for firmware < 123

0.0.3.0
Resize groups on display tab to prevent text clipping

0.0.2.9
Change Pg1-Pg7 on display to to meaningful text

0.0.2.8
tz.h added to allow set/change/read user time zone code
Add timezone list box for selecting time zone
Add NTP UTC
Add NTP Time Zone string
Add background load timer to get non-sensor data at timed intervals
Add form to get users choice for color of background load tasks
Change page display string to check boxes
Change loading of data on connect - only load sensor data
Change forms ntp/display/mqtt/gps/rtc/sky-k1-k7/toc/tc/cfp for delayed load
Fix for Clearall and Setall on custom logging tab not working
Remove gmtoffsetseconds and daylightoffsetseconds to NTP tab
Remove old time zone settings
Remove log interval 15s

0.0.2.7
Upgrade to firmware 125-4
Remove TimeZone from NTP tab
Add gmtoffsetseconds and daylightoffsetseconds to NTP tab
Remove NTP Query time and NTP Sync Hour from NTP tab
Add NTP Sync Interval to NTP tab
Add shortcut key ALT+W for Wind tab
Fix for auto log interval not being set correctly

0.0.2.6 22-Nov-2021
Add option on RTC tab to send computer date/time to controller
Fix for sending rtc date/time in wrong format

0.0.2.5
Fix for shortcut M not going to Main tab

0.0.2.4
Add reconnect timer in case auto-connect failed
Consolidate code
Fix for Ping success form showing error icon

0.0.2.3
Add auto connect and auto logging options
Add user specified custom log filename 

0.0.2.2
Add compass direction indicator to Wind tab

0.0.2.1
Add Start/Stop webserver, and Get webserver status [requires firmware 124-4 or higher]
Remove compass dial indicator from Wind tab

0.0.2.0
Rename NTP Sync Time to NTP Sync Hour on NTP tab

0.0.1.9
Remove gpsformat

0.0.1.7
Ensure that all logged data element names conform to that laid out in the PDF

0.0.1.6
Fix for json log file unterminated on makehay

0.0.1.5
Fix for set tls correction factor
Remove MQTT JSON support
Add Send on connect GPS options
Add custom logging tab
Support for make hay and system uptime
Fix for not disconnecting when controller returns null or incorrect data
Add GPS static coordinates on GPS tab
Add GPS Truncate, Static and Format (decimal/degree) to GPS tab

0.0.1.4
Add system up time [Connection tab]

0.0.1.3
Add TLS sensor correction factor to tls tab

0.0.1.2
Fix for Rainfall_prev_hr showing incorrect values

0.0.1.1
Change filename and logged data date/time from dd-MM-yyyy to yyyy-MM-dd
Change filenames from mySQMPLUS to mySQMPlus
Fix for gpsdata in log files
Add Shortcut keys and Menu for Shortcuts

0.0.1.0
Fix for page display option string on display tab obscuring text
Fix for CSII logging issues
Fix for datalogfile (not CSII) output format (change xx,xx to xx.xx) - override locale settings
Fix for locale issues (RainVolts) causing problems with Excel loading logfiles
Fix for Cloud Model tab, CFP, TC and TOC values wrong type and invalid checking
Fix for IntervalTimer logging issue
Add rain tipping bucket data to datalog file
Add CSII settings page for boundary checks when generating CSII log file

0.0.0.24
Fix for Exit dialog choices being ignored

0.0.0.23
Add connection status to main form
Add status for logging timer (logging tab)
Fix for date/time in CSII log file
Change MLX9014 tab name to Cloud Model

0.0.0.22
Fix for MQTT system call when connecting

0.0.0.20
Fix for Get MQTT Publish topic
Add MQTT Subscribe topic to MQTT tab
Add MQTT data to retrieve from controller when connecting

0.0.0.20
Fix for Get MQTT Publish topic
Add MQTT Subscribe topic to MQTT tab
Add MQTT data to retrieve from controller when connecting
THIS IS A MAJOR UPDATE.
UNINSTALL APP USING CONTROL PANEL BEFORE INSTALLING THIS VERSION

0.0.0.19
Change logging tab, to use Start and Stop data logging buttons

0.0.0.18
Fix for connection issues

0.0.0.16
Change to CloudCover for CSII/Boltwood files - now using 3 cloud states

0.0.0.15
Fix serial usb issues
Remove tsl2591 tab

0.0.0.14
Prevent resizing of Ping form

0.0.0.13
/Make sure cloud sensor data file is single line and new data overwrites old data

0.0.0.12
REMOVE OLD VERSION USING CONTROL PANEL BEFORE INSTALLING THIS VERSION
Fix for Rain Timer causing disonnect from controller\

0.0.0.11
REMOVE OLD VERSION USING CONTROL PANEL BEFORE INSTALLING THIS VERSION
Fix for runtime error getting rtc values
Fix for Set NTP button sending wrong values
Fix for error in get rtc utp date/time 
Fix for Serial DelayOnConnect not working
Add © symbol
Add pagedisplayoption saved/restored in/from Windows profile
Add Send on Connect group on Interface tab
Rewrite event handler for DisplayPageOption string
Change TempMode and DistanceMode buttons on Connection tab to Checkboxes
Delete Graph button and place Graph Window under Utils menu option

0.0.0.10
For for some values being truncated
Fix for some MQTT values causing exception errors

0.0.0.9
Fix for connection issue when ENABLENTP is enabled in firmware

0.0.0.8
Add additional connection messages
Fix for text entry of ntp servername

0.0.0.7
Add edit/update settings for MQTT, RTC and NTP to controller

0.0.0.6
Fix connection issues
Change name OLED tab to Display tab

0.0.0.5
Fix for text clipped on Connection tab

0.0.0.4
Rearrange Connection tab

0.0.0.3
Add Utils menu
Add Ping

0.0.0.2
Remove TCP/IP related options from Settings menu
Fix for Serial Read timeout not being applied
Fix for DelayOnConnect not being applied

0.0.0.1
Change to app - support both TCP/IP and Serial in this application
Initial release

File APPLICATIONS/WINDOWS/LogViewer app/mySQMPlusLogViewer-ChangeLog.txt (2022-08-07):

mySQM+ Log Viewer Application
© Robert Brown, 2020-2021
All rights reserved

0.0.0.6
Add average wind speed
Add max wind gust

0.0.0.5
fix for issues with zoom at 200, 500, 1000

0.0.0.4
Changes to json parsing, adjusted to conform to key names/value pairs as outlined in PDF

0.0.0.3
Add datpoint tab, show/hide datapoint values
Add reload data log file option
Add additional zoom buttons to handle a large number of data points
Add controller info to Loadtab

0.0.0.2
Rewrite of original code
Add JSON file handling to support mySQM+ JSON LOGGER application

0.0.0.1
Initial release
